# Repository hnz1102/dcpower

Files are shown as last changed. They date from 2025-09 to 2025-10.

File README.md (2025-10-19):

<div align="center">
  <h1><code>DC Power Unit for Breadboard</code></h1>
  <p>
    
  </p>
</div>

# DC Power Unit for Breadboard

This is a DC Power Unit for Breadboard based on ESP32-S3 microcontroller and AP33772S USB Power Delivery (PD) Sink Controller. It can supply power to the breadboard from USB Power Delivery (PD) Charger with support for both Standard Power Range (SPR) and Extended Power Range (EPR) modes. The output voltage can be controlled from 0v to 20V in SPR mode and up to 28V(*1) in EPR mode with step of 10mV.   
There are 2 types of adopters for the output terminal: Single positive power output terminal and dual positive/negative output terminal. It is easy to connect to the breadboard with standard 2.54mm pitch pin header. If you select the dual positive/negative output terminal adopter, the output voltage can be halved by positive and negative voltage. E.g. If you set the output voltage to 20V, you can get +10V and -10V from the positive and negative output terminal.

***1: Maximum voltage is limited to 28V by AP33772S hardware specifications. Some PD chargers may not support EPR mode or only support up to 16V/5A. Please check your PD charger specifications.**

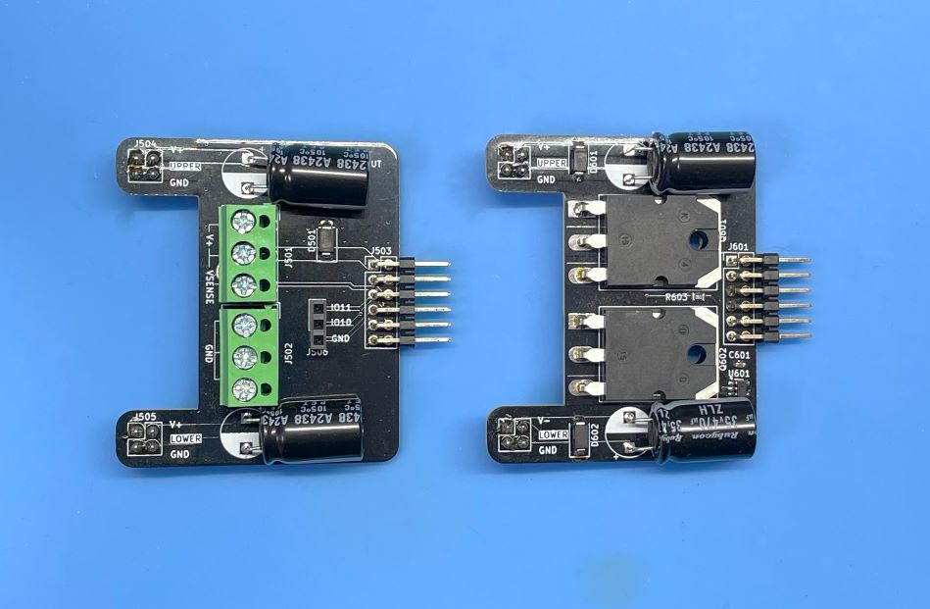
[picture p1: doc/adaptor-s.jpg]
adopter


The left image shows the single positive output terminal adopter, and the right image shows the dual positive/negative output terminal adopter.

## Key Features

- **High Power Delivery**: Up to 100W from USB PD Charger
- **Multiple Voltage Outputs**: 0V to 20V in SPR mode, 0V to 28V in EPR mode (10mV steps)
- **High Current Support**: Up to 5A when PD Charger supports EPR, but some chargers support up to 90% of the maximum current.
- **Touch Control Interface**: Front panel touch switch for voltage selection and output control
- **Precise Control**: PID controller maintains constant output voltage
- **High Accuracy Monitoring and Control**: 10mV voltage accuracy using shunt resistor and INA228 current sensor, with 1mV resolution.
- **Real-time Display**: OLED display shows voltage, current, power consumption, and temperature
- **Data Logging**: WiFi connectivity for sending measurement data to InfluxDB server
- **Web Dashboard**: Data visualization using InfluxDB dashboard
- **Safety Features**: Over Voltage Protection (OVP), Under Voltage Protection (UVP), Over Current Protection (OCP). Over Temperature Protection (OTP) does not implemented.

****Note**: If you use 21V or higher voltage, input voltage is 28v or higher, and differential voltage is over 3V and output current is over 3A, the MOSFET device is in the high consumption state and the unit temperature may rise over 80 degrees Celsius. Please be careful about the temperature. You can set the maximum temperature in the configuration file. The default value is 80 degrees Celsius. If the temperature exceeds the limit, the output will be disabled automatically. I recommend using less than 0.7A current at 21V or higher voltage. Otherwise, if you set the output voltage to 27V or higher, the temperature rise is not a problem.**

****Note**: This unit uses a micro controller and a USB PD controller. These controllers need the power to operate. Therefore, if you use a over current, the power source may be shut down by the over current protection of the PD charger. In this case, This unit cannot operate and will be turned off. Please use the current within the specification of your PD charger.**

## Hardware Components

- **ESP32-S3-WROOM-1-N16R8**: Main microcontroller
- **AP33772S**: USB Power Delivery Sink Controller with EPR support
- **INA228**: High-precision current/voltage sensor
- **SSD1331**: Color OLED display (96x64 pixels)
- **Touch Interface**: Capacitive touch sensors for user interaction
- **MOSFET Load Circuit**: Electronic load for testing and regulation

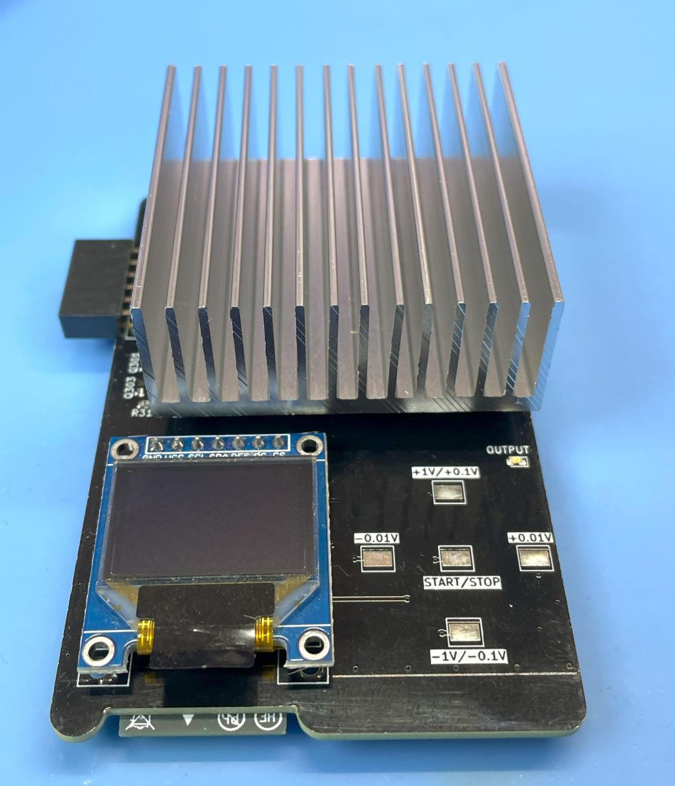
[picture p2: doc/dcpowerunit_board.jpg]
board


## Software Architecture

The firmware is written in Rust using the ESP-IDF framework and consists of several modules:

- `main.rs`: Main application logic and system initialization
- `usbpd.rs`: AP33772S USB-PD driver interface using the ap33772s-driver crate
- `displayctl.rs`: OLED display control and user interface
- `currentlogs.rs`: Current and voltage measurement using INA228
- `touchpad.rs`: Touch sensor interface and user input handling
- `pidcont.rs`: PID controller for voltage regulation
- `wifi.rs`: WiFi connectivity and network management
- `transfer.rs`: Data transmission to InfluxDB server
- `syslogger.rs`: System logging functionality

ap33772s-driver crate is used for USB-PD communication with the AP33772S controller. Please see the [ap33772s-driver](https://github.com/hnz1102/ap33772s-driver) for more details.

## How to Use the Unit

### Basic Operation

1. **Connection**: Connect a USB-C PD charger to the input port
2. **Power On**: The unit automatically detects the PD source and displays available power profiles
3. **Voltage Selection**: Use the touch interface to select desired output voltage
4. **Output Control**: Press the center touch position to enable/disable output
5. **Monitoring**: View real-time measurements on the OLED display

### Touch Interface Controls

- **Up/Down Touch**: Increase or decrease output voltage in 100mV steps, long press for 1V steps
- **Left/Right Touch**: Increase or decrease output voltage in 10mV steps
- **Center Touch**: Long press to toggle output ON/OFF
- **Display Information**: Shows current voltage, current, power, unit temperature, and WiFi status

**If the output is disabled due to over current, over power, or over temperature, you can clear the error message by pressing the center touch position once.**

### Safety Features

- Under Voltage Protection (UVP)
- Over Voltage Protection (OVP) 
- Over Current Protection (OCP)
- Automatic fault detection and shutdown

These protections are implemented by the AP33772S.

## Dependencies and Crates

The project uses the custom `ap33772s-driver` crate for USB-PD communication:

```toml
[dependencies]
ap33772s-driver = { version = "0.1.4", features = ["std"] }
```

Other key dependencies include:
- `esp-idf-hal` v0.45.2: ESP32 hardware abstraction
- `embedded-hal` v1.0.0: Platform-agnostic hardware interfaces
- `ssd1331` v0.3.0: OLED display driver
- `embedded-graphics` v0.7: Graphics primitives for display
- `chrono` v0.4.38: Date and time handling
- `toml-cfg` v0.1.3: Configuration file parsing

# How to build from code and Install to the unit.

Using Ubuntu 22.04.3 LTS and ESP-IDF V5.4.2

## Prerequisites
Ensure that your system meets the following requirements before proceeding with the installation:
- Operating System: Linux-based distribution
- Required Packages: git, python3, python3-pip, gcc, build-essential, curl, pkg-config, libudev-dev, libtinfo5, clang, libclang-dev, llvm-dev, udev, libssl-dev, python3.10-venv

## Installation Steps

### 1. System Update and Package Installation
Update your system and install the necessary packages using:
```bash
sudo apt update && sudo apt -y install git python3 python3-pip gcc build-essential curl pkg-config libudev-dev libtinfo5 clang libclang-dev llvm-dev udev libssl-dev python3.10-venv
```

### 2. Rust Installation
Install Rust programming language and Cargo package manager:
```bash
curl --proto '=https' --tlsv1.2 -sSf https://sh.rustup.rs | sh
```
After installation, activate Rust by sourcing the environment:
```bash
. "$HOME/.cargo/env"
```

### 3. Additional Tools Installation
Install the following Rust tools:
- ldproxy
- espup
- cargo-espflash

Use the following commands:
```bash
cargo install ldproxy
cargo install espup
cargo install cargo-espflash
```

At this time (2025-07-25), espup cannot be compiled. If you get an error, please use the following command to install the toolchain.
```bash
cargo install cargo-binstall
cargo binstall espup
```

### 4. ESP Environment Setup
Run the following command to install and update the Espressif Rust ecosystem:
```bash
espup install
espup update
```
Set up environment variables:
```bash
. ./export-esp.sh
```

### 5. Udev Rules Configuration
Configure udev rules for device permissions:
```bash
sudo sh -c 'echo "SUBSYSTEMS==\"usb\", ATTRS{idVendor}==\"303a\", ATTRS{idProduct}==\"1001\", MODE=\"0666\"" > /etc/udev/rules.d/99-esp32.rules'
sudo udevadm control --reload-rules
sudo udevadm trigger
```

### 6. Clone Repository
Clone the DC Power Unit repository:
```bash
git clone https://github.com/hnz1102/dcpower.git
cd dcpower/code
```

### 7. Setting WiFi SSID, Password, etc.
Change the following configuration file: `cfg.toml`
You have to set the following parameters: WiFi SSID, Password, InfluxDB Server IP Address, InfluxDB API Key, and InfluxDB API with your ORG.
You can get the API Key from the InfluxDB Web Console. Please see the 'How to Install the InfluxDB and Configure the Dashboard' section No.3.

```toml
[dcpowerunit]
wifi_ssid = "<Your AP SSID>"  # Set your AP SSID
wifi_psk = "<Your AP Password>" # Set your AP Password
influxdb_server = "<InfluxDB Server IP Address:Port>" # Set your InfluxDB Server IP Address and Port ex. 192.168.1.100:8086
pid_kp = "0.0000005"
pid_ki = "0.00002"
pid_kd = "0.1"
pwm_offset = "0"
pd_config_offset = "1.5"
shunt_resistance = "0.005"
shunt_temp_coefficient = "50"
max_current_limit = "5.2"
max_power_limit = "100.0"
max_temperature_limit = "75" # Set the maximum temperature limit in degrees Celsius. Default is 75 degrees.
influxdb_api_key = "<InfluxDB API KEY>" # Set your InfluxDB API Key
influxdb_api = "/api/v2/write?org=<ORG>&bucket=LOGGER&precision=ns" # Set your InfluxDB API with your ORG and BUCKET
influxdb_tag = "dcpowerunit"  # Tag for InfluxDB measurements
influxdb_measurement = "dcpowerunit" # Measurement name for InfluxDB
syslog_server = "<Syslog Server IP Address:Port>" # Set your Syslog Server IP Address and Port ex. 192.168.2.140:514
syslog_enable = "false" # Set to "true" to enable syslog
```

### 8. Build and Flash
Build the project:
```bash
cargo build --release
```

### 9. Flash the Firmware
Connect the DC Power Unit to your PC using a USB cable. Then, flash the firmware:
```bash
cargo espflash flash --release --monitor
```

If your device is not detected, power on the device and during the boot, press the `BOOT` button.
Then, run the flash command again.

### 10. Monitor the Output
After flashing the firmware, the console shows the booting messages and system initialization including:
- WiFi connection status
- AP33772S USB-PD controller initialization
- Available PDO (Power Data Object) detection
- Touch interface activation
- OLED display initialization
```bash
Chip type:         esp32s3 (revision v0.2)
Crystal frequency: 40 MHz
Flash size:        16MB
Features:          WiFi, BLE, Embedded Flash
MAC address:       80:65:99:b8:8e:90
App/part. size:    1,383,760/1,536,000 bytes, 90.09%
[00:00:00] [========================================]      14/14      0x0      Verifying... OK!                   
[00:00:00] [========================================]       1/1       0x8000   Skipped! (checksum matches)        
[00:00:15] [========================================]     864/864     0x10000  Verifying... OK!                   
[2025-09-15T07:23:38Z INFO ] Flashing has completed!
Commands:
    CTRL+R    Reset chip
    CTRL+C    Exit

ESP-ROM:esp32s3-20210327
Build:Mar 27 2021
rst:0x15 (USB_UART_CHIP_RESET),boot:0x8 (SPI_FAST_FLASH_BOOT)
Saved PC:0x40378d03
0x40378d03 - setup_priv_desc$isra$0
    at ??:??
SPIWP:0xee
mode:DIO, clock div:2
load:0x3fce2810,len:0x1564
load:0x403c8700,len:0x4
load:0x403c8704,len:0xd24
load:0x403cb700,len:0x2ed4
entry 0x403c8928
I (27) boot: ESP-IDF v5.4.2 2nd stage bootloader
I (27) boot: compile time Sep 15 2025 07:22:33
I (27) boot: Multicore bootloader
I (28) boot: chip revision: v0.2
I (30) boot: efuse block revision: v1.3
I (34) boot.esp32s3: Boot SPI Speed : 40MHz
I (38) boot.esp32s3: SPI Mode       : DIO
I (41) boot.esp32s3: SPI Flash Size : 16MB
I (45) boot: Enabling RNG early entropy source...
I (50) boot: Partition Table:
I (52) boot: ## Label            Usage          Type ST Offset   Length
I (59) boot:  0 nvs              WiFi data        01 02 00009000 00006000
I (65) boot:  1 phy_init         RF data          01 01 0000f000 00001000
I (72) boot:  2 factory          factory app      00 00 00010000 00177000
I (78) boot: End of partition table
I (81) esp_image: segment 0: paddr=00010020 vaddr=3c0f0020 size=4b244h (307780) map
I (164) esp_image: segment 1: paddr=0005b26c vaddr=3fc9c700 size=04dach ( 19884) load
I (170) esp_image: segment 2: paddr=00060020 vaddr=42000020 size=e89e8h (952808) map
I (404) esp_image: segment 3: paddr=00148a10 vaddr=3fca14ac size=00bfch (  3068) load
I (406) esp_image: segment 4: paddr=00149614 vaddr=40374000 size=186f0h (100080) load
I (437) esp_image: segment 5: paddr=00161d0c vaddr=600fe000 size=0001ch (    28) load
I (447) boot: Loaded app from partition at offset 0x10000
I (447) boot: Disabling RNG early entropy source...
I (457) octal_psram: vendor id    : 0x0d (AP)
I (457) octal_psram: dev id       : 0x02 (generation 3)
I (458) octal_psram: density      : 0x03 (64 Mbit)
I (460) octal_psram: good-die     : 0x01 (Pass)
I (464) octal_psram: Latency      : 0x01 (Fixed)
I (468) octal_psram: VCC          : 0x01 (3V)
I (472) octal_psram: SRF          : 0x01 (Fast Refresh)
I (477) octal_psram: BurstType    : 0x01 (Hybrid Wrap)
I (482) octal_psram: BurstLen     : 0x01 (32 Byte)
I (487) octal_psram: Readlatency  : 0x02 (10 cycles@Fixed)
I (492) octal_psram: DriveStrength: 0x00 (1/1)
I (497) MSPI Timing: PSRAM timing tuning index: 5
I (500) esp_psram: Found 8MB PSRAM device
I (504) esp_psram: Speed: 80MHz
I (507) cpu_start: Multicore app
I (522) cpu_start: Pro cpu start user code
I (522) cpu_start: cpu freq: 160000000 Hz
I (522) app_init: Application information:
I (522) app_init: Project name:     libespidf
I (526) app_init: App version:      100adf2
I (530) app_init: Compile time:     Sep 15 2025 07:22:02
I (535) app_init: ELF file SHA256:  000000000...
I (539) app_init: ESP-IDF:          v5.4.2
I (543) efuse_init: Min chip rev:     v0.0
I (547) efuse_init: Max chip rev:     v0.99 
I (551) efuse_init: Chip rev:         v0.2
I (555) heap_init: Initializing. RAM available for dynamic allocation:
I (561) heap_init: At 3FCA6A48 len 00042CC8 (267 KiB): RAM
I (566) heap_init: At 3FCE9710 len 00005724 (21 KiB): RAM
I (571) heap_init: At 3FCF0000 len 00008000 (32 KiB): DRAM
I (576) heap_init: At 600FE01C len 00001FCC (7 KiB): RTCRAM
I (582) esp_psram: Adding pool of 8192K of PSRAM memory to heap allocator
I (589) spi_flash: detected chip: gd
I (592) spi_flash: flash io: dio
W (595) pcnt(legacy): legacy driver is deprecated, please migrate to `driver/pulse_cnt.h`
W (602) i2c: This driver is an old driver, please migrate your application code to adapt `driver/i2c_master.h`
W (612) timer_group: legacy driver is deprecated, please migrate to `driver/gptimer.h`
I (620) sleep_gpio: Configure to isolate all GPIO pins in sleep state
I (626) sleep_gpio: Enable automatic switching of GPIO sleep configuration
I (633) main_task: Started on CPU0
I (643) esp_psram: Reserving pool of 32K of internal memory for DMA/internal allocations
I (643) main_task: Calling app_main()
I (653) gpio: GPIO[15]| InputEn: 0| OutputEn: 0| OpenDrain: 0| Pullup: 0| Pulldown: 0| Intr:0 
I (653) gpio: GPIO[16]| InputEn: 0| OutputEn: 0| OpenDrain: 0| Pullup: 0| Pulldown: 0| Intr:0 
I (663) gpio: GPIO[46]| InputEn: 0| OutputEn: 0| OpenDrain: 0| Pullup: 0| Pulldown: 0| Intr:0 
I (683) pp: pp rom version: e7ae62f
I (683) net80211: net80211 rom version: e7ae62f
I (693) wifi:wifi driver task: 3fcc44a0, prio:23, stack:6656, core=0
I (693) wifi:wifi firmware version: bea31f3
I (693) wifi:wifi certification version: v7.0
I (693) wifi:config NVS flash: disabled
I (693) wifi:config nano formatting: disabled
I (703) wifi:Init data frame dynamic rx buffer num: 32
I (703) wifi:Init static rx mgmt buffer num: 5
I (713) wifi:Init management short buffer num: 32
I (713) wifi:Init dynamic tx buffer num: 32
I (723) wifi:Init static tx FG buffer num: 2
I (723) wifi:Init static rx buffer size: 1600
I (723) wifi:Init static rx buffer num: 10
I (733) wifi:Init dynamic rx buffer num: 32
I (733) wifi_init: rx ba win: 6
I (733) wifi_init: accept mbox: 6
I (743) wifi_init: tcpip mbox: 32
I (743) wifi_init: udp mbox: 6
I (743) wifi_init: tcp mbox: 6
I (753) wifi_init: tcp tx win: 5760
I (753) wifi_init: tcp rx win: 5760
I (753) wifi_init: tcp mss: 1440
I (763) wifi_init: WiFi IRAM OP enabled
I (763) wifi_init: WiFi RX IRAM OP enabled
I (773) phy_init: phy_version 701,f4f1da3a,Mar  3 2025,15:50:10
I (803) wifi:mode : sta (80:65:99:b8:8e:90)
I (803) wifi:enable tsf
I (3313) wifi:new:<8,0>, old:<1,0>, ap:<255,255>, sta:<8,0>, prof:1, snd_ch_cfg:0x0
I (3313) wifi:state: init -> auth (0xb0)
I (3313) wifi:state: auth -> assoc (0x0)
I (3323) wifi:state: assoc -> run (0x10)
I (3333) wifi:connected with Buffalo-G-1AD0, aid = 4, channel 8, BW20, bssid = c4:3c:ea:df:1a:d0
I (3333) wifi:security: WPA2-PSK, phy: bgn, rssi: -51
I (3333) wifi:pm start, type: 1

I (3333) wifi:dp: 1, bi: 102400, li: 3, scale listen interval from 307200 us to 307200 us
I (3343) wifi:set rx beacon pti, rx_bcn_pti: 0, bcn_timeout: 25000, mt_pti: 0, mt_time: 10000
I (3423) wifi:AP's beacon interval = 102400 us, DTIM period = 1
I (5353) esp_netif_handlers: sta ip: 192.168.2.142, mask: 255.255.255.0, gw: 192.168.2.1
I (9063) wifi:<ba-add>idx:0 (ifx:0, c4:3c:ea:df:1a:d0), tid:0, ssn:3, winSize:64
I (13373) wifi:<ba-add>idx:1 (ifx:0, c4:3c:ea:df:1a:d0), tid:2, ssn:0, winSize:64
I (13383) gpio: GPIO[18]| InputEn: 0| OutputEn: 0| OpenDrain: 0| Pullup: 0| Pulldown: 0| Intr:0 
I (13393) gpio: GPIO[9]| InputEn: 0| OutputEn: 0| OpenDrain: 0| Pullup: 0| Pulldown: 0| Intr:0 
```

## How to Install the influxDB and Configure the Dashboard

### 1. Download [influxDB](https://docs.influxdata.com/influxdb/v2.7/install/?t=Linux) and Install.
```bash
$ wget https://dl.influxdata.com/influxdb/releases/influxdb2-2.7.0-amd64.deb
$ sudo dpkg -i influxdb2-2.7.0-amd64.deb
$ sudo service influxdb start
```

### 2. Configure the influxDB

```
Connect to the 'http://<influxDB installed PC Address>:8086'
```
Click `GET STARTED` and set `Username`, `Password`, `Initial Organization Name`, and `Initial Bucket Name`
|Term|Value|
|---|---|
|Username|Set login username as influxDB administrator web console|
|Password|Set login password as influxDB administrator web console|
|Initial Organization Name| Organization Name ex. ORG|
|Initial Bucket Name| LOGGER |

After set them, click `CONTINUE`.

### 3. Copy the operator API token.

You can see the operator API token on the browser. YOU WON'T BE ABLE TO SEE IT AGAIN!
If you want to get new API token, click `API Tokens` menu form `Sources` Icon, then click `GENERATE API TOKEN` and select `All access token`, click `Save`.
You can see a new API token and get it.
After copy the token, click `CONFIGURE LATER`.

### 4. Import the Dashboard Template.

Click the `Dashboard` icon, and select `Import Dashboard` from the `CREATE DASHBOARD` menu.

Drop the `influxdb/dc_power_station.json` file to `Drop a file here`, then click `IMPORT JSON AS DASHBOARD`.

You can see the `DC POWER STATION` pannel on the Dashboards page.

Click this panel, and You can see the dashboard.

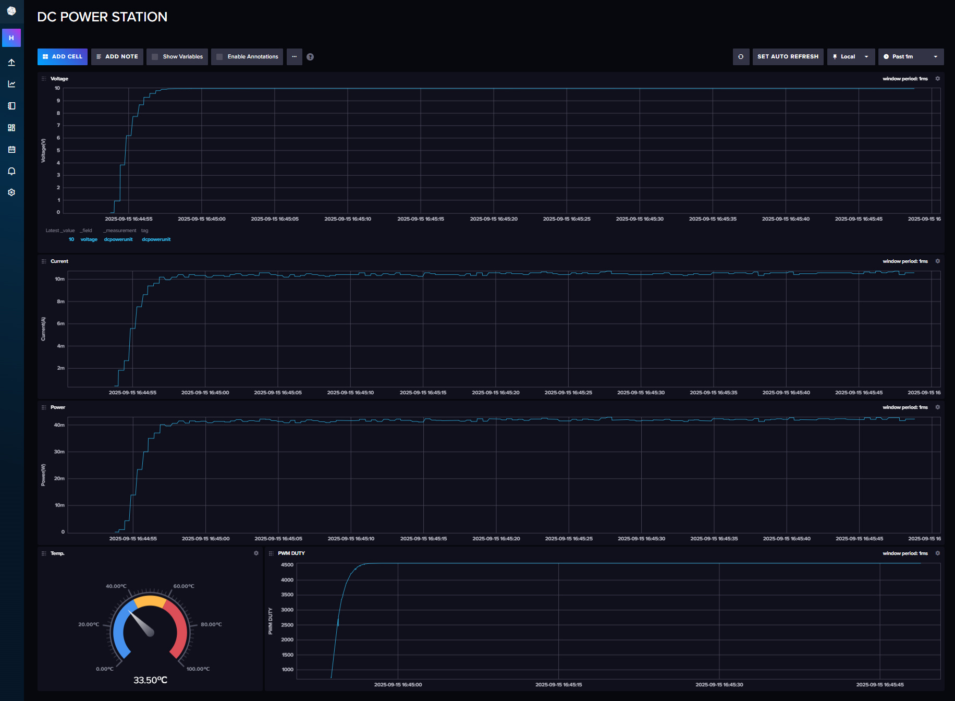
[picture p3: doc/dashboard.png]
dashboard


If you want to customize the dashboard design, click configure mark. You can change the graph design.

## Schematic, PCB Gabar Data

There is a Schematic data in hardware directory. 

This PCB is designed by [Kicad](https://www.kicad.org/). 

## LICENSE
This source code is licensed under MIT. Other Hardware Schematic documents are licensed under CC-BY-SA V4.0.

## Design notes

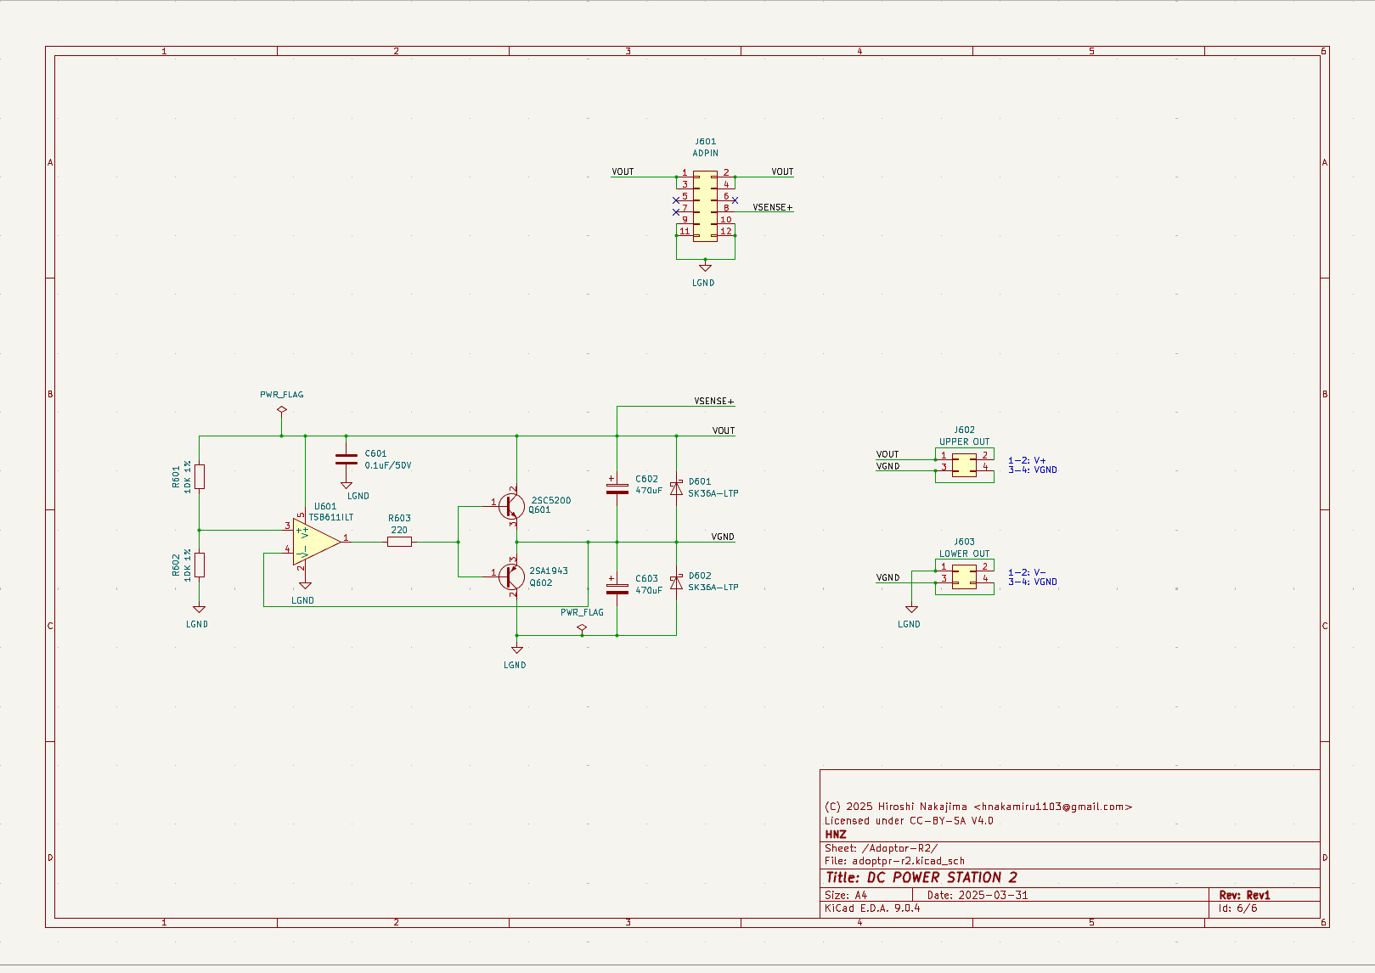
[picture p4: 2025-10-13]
doc/schematic5.png

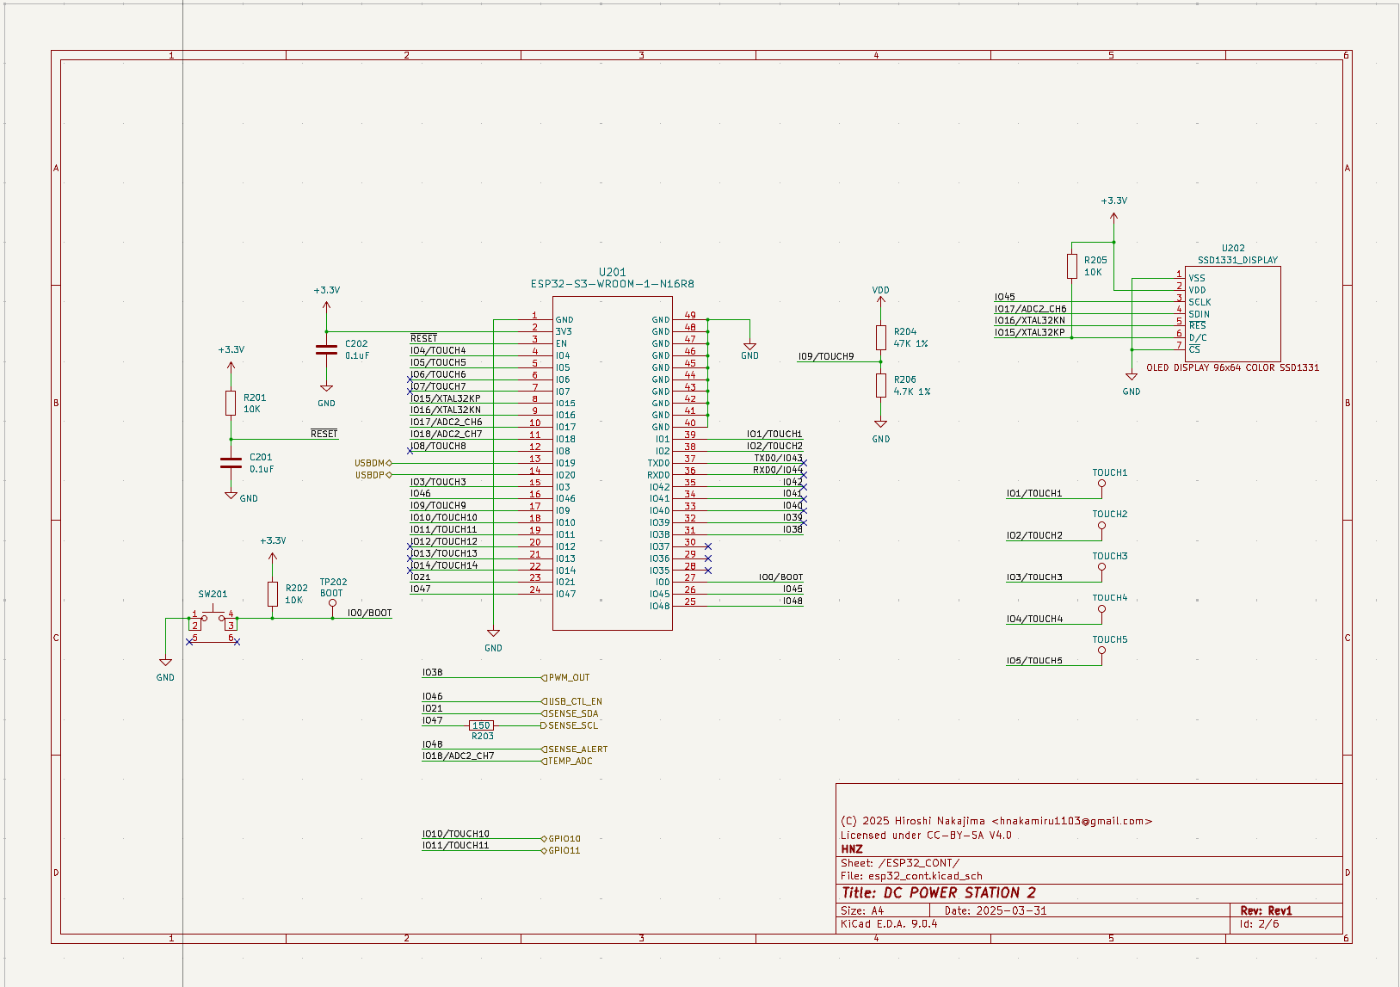
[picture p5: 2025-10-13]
doc/schematic2.png

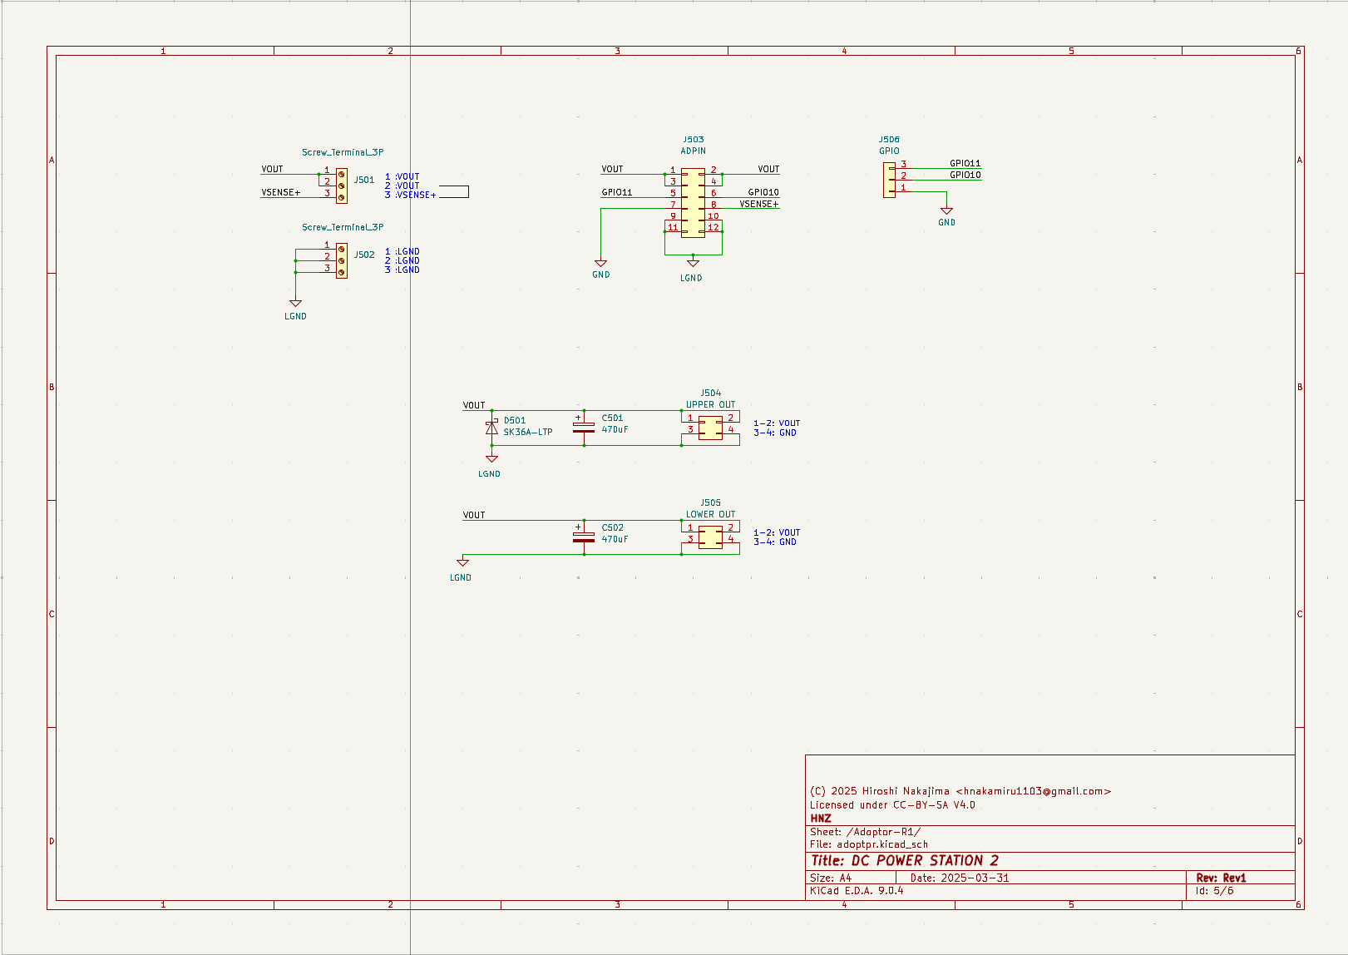
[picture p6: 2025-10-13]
doc/schematic4.png

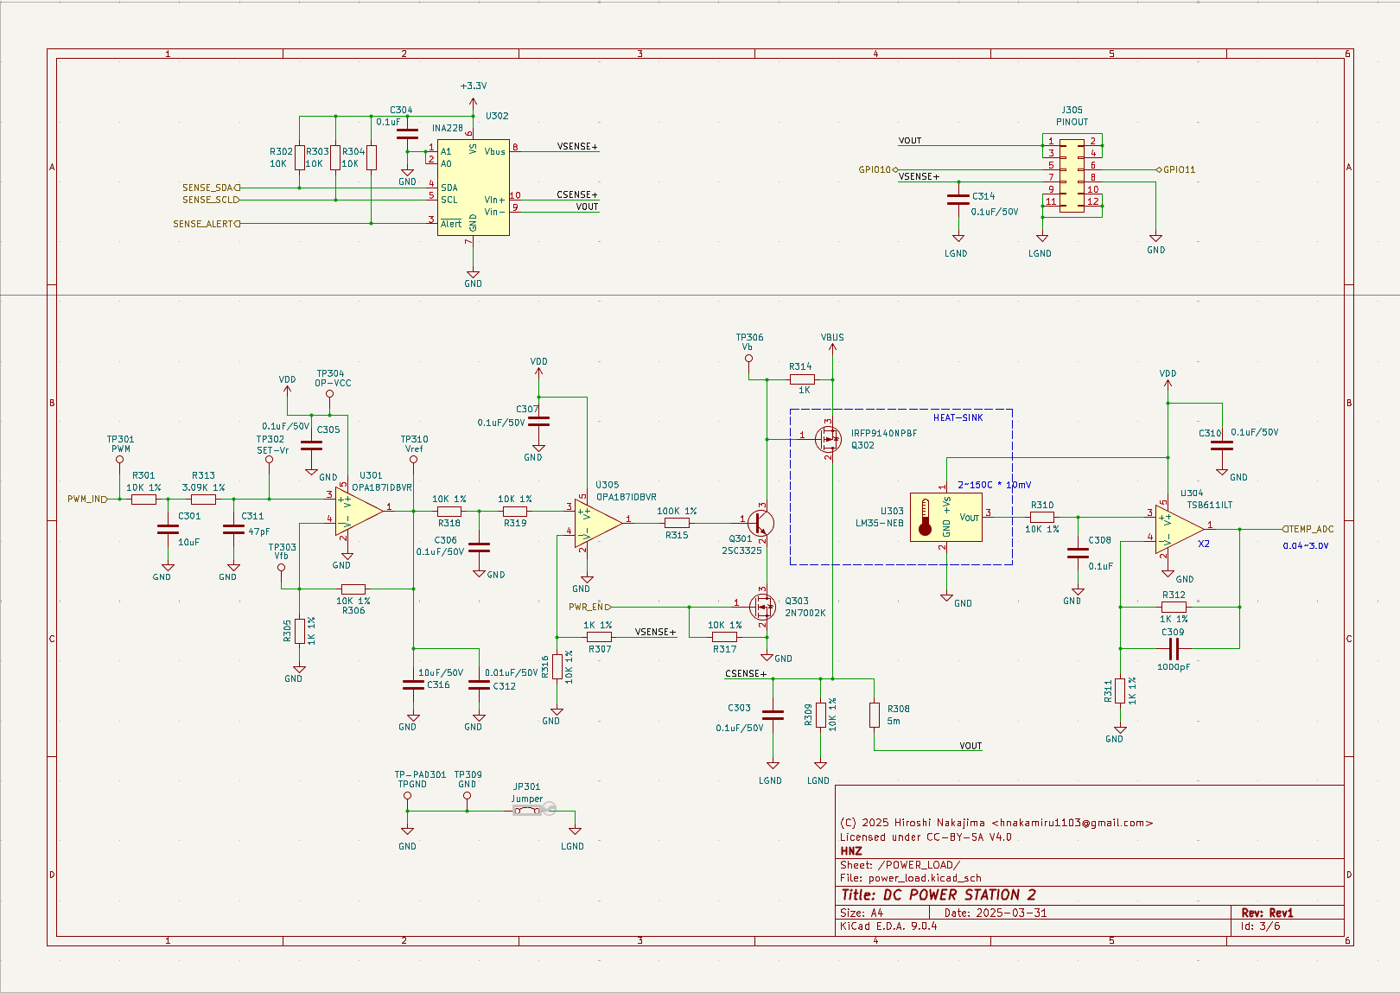
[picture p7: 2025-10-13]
doc/schematic3.png

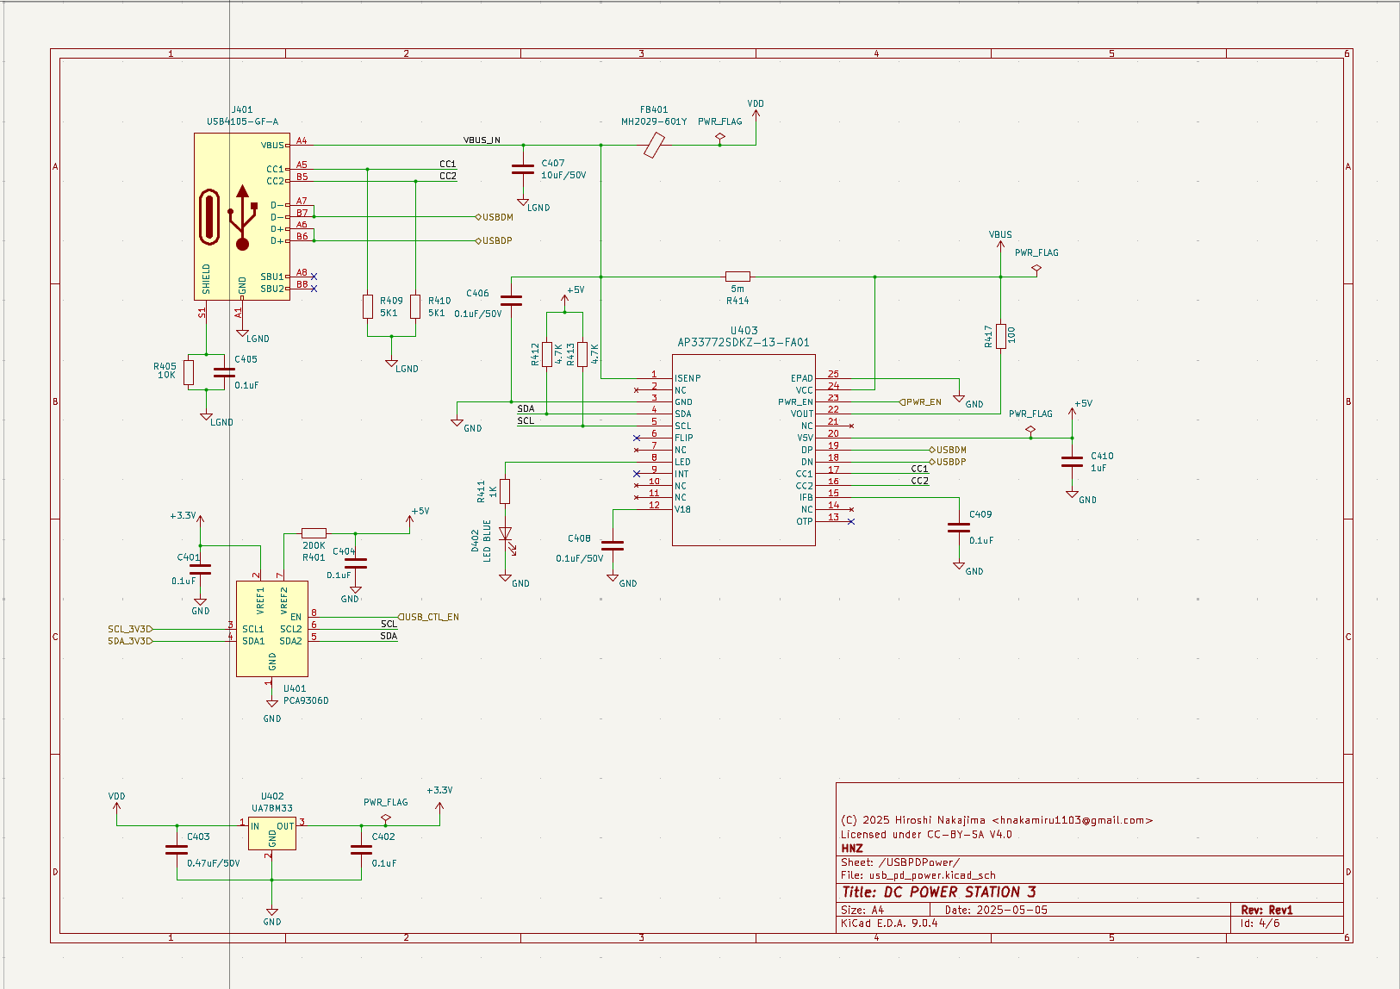
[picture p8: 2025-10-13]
doc/schematic1.png

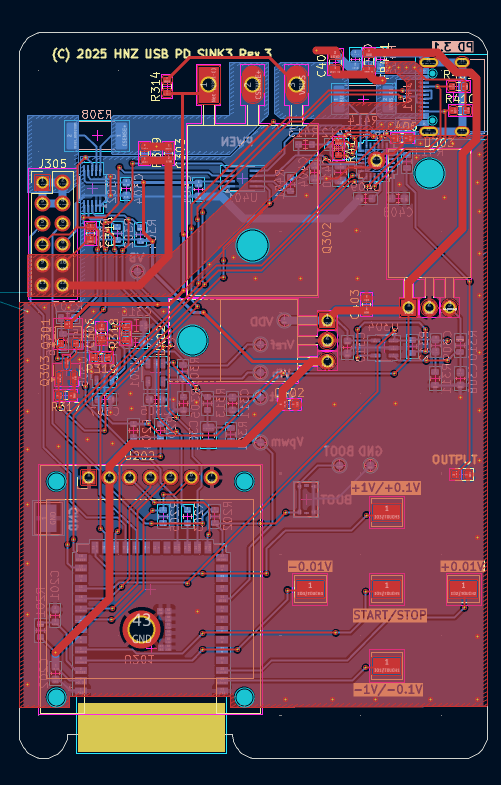
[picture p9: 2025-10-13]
doc/main-pcb.png

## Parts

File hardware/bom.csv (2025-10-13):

Reference | Value | Datasheet | Footprint | Qty | DNP | digikey | distributor | storeURL
C201,C202,C304,C308,C401,C402,C404,C405,C409 | 0.1uF | ~ | Capacitor_SMD:C_0603_1608Metric | 9 |  | 311-1343-1-ND | https://www.digikey.com/en/products/detail/yageo/CC0603ZRY5V9BB104/2103081
C301 | 10uF | ~ | Capacitor_SMD:C_0805_2012Metric | 1 |  | 490-6473-1-ND | https://www.digikey.com/en/products/detail/murata-electronics/GRM21BR61C106KE15K/2546903
C303,C305,C306,C307,C310,C314,C406,C408,C601 | 0.1uF/50V | ~ | Capacitor_SMD:C_0603_1608Metric | 9 |  | 311-1343-1-ND | https://www.digikey.com/en/products/detail/yageo/CC0603ZRY5V9BB104/2103081
C309 | 1000pF | ~ | Capacitor_SMD:C_0603_1608Metric | 1 |  | 311-1080-1-ND | https://www.digikey.com/en/products/detail/yageo/CC0603KRX7R9BB102/302814
C311 | 47pF | ~ | Capacitor_SMD:C_0603_1608Metric | 1 |  | 311-3980-1-ND | https://www.digikey.com/en/products/detail/yageo/CC0603JRNPOABN470/5883631
C312 | 0.01uF/50V | ~ | Capacitor_SMD:C_0603_1608Metric | 1 |  | 311-1085-1-ND | https://www.digikey.com/en/products/detail/yageo/CC0603KRX7R9BB103/302819
C316,C407 | 10uF/50V | ~ | Capacitor_SMD:C_0805_2012Metric | 2 |  | 490-18663-1-ND | https://www.digikey.com/en/products/detail/murata-electronics/GRM21BR61H106KE43L/10326316
C403 | 0.47uF/50V | ~ | Capacitor_SMD:C_0603_1608Metric | 1 |  | 587-3170-1-ND | https://www.digikey.com/en/products/detail/taiyo-yuden/UMK107B7474KA-TR/3194963
C410 | 1uF | ~ | Capacitor_SMD:C_0805_2012Metric | 1 |  | 311-1365-1-ND | https://www.digikey.jp/en/products/detail/yageo/CC0805KKX7R7BB105/2103103
C501,C502,C602,C603 | 470uF | ~ | Capacitor_THT:CP_Radial_D8.0mm_P5.00mm | 4 |  | 1189-1890-ND | https://www.digikey.jp/en/products/detail/rubycon/35ZLH470MEFC10X16/3563723
D402 | LED BLUE | ~ | LED_SMD:LED_0603_1608Metric | 1 |  | 3147-B1931NB--20C007614U1930CT-ND | https://www.digikey.jp/en/products/detail/harvatek-corporation/B1931NB-20C007614U1930/15861263
D501,D601,D602 | SK36A-LTP |  | Diode_SMD:D_SMA | 3 |  | SK36A-LTPMSCT-ND | https://www.digikey.com/en/products/detail/mcc-micro-commercial-components/SK36A-LTP/2642025
FB401 | MH2029-601Y | ~ | Inductor_SMD:L_0805_2012Metric | 1 |  | MH2029-601YCT-ND | https://www.digikey.com/en/products/detail/bourns-inc/MH2029-601Y/3741762
J305 | PINOUT | ~ | Connector_PinHeader_2.54mm:PinHeader_2x06_P2.54mm_Vertical | 1 |  | PPPC062LJBN-RC | https://www.digikey.com/en/products/detail/sullins-connector-solutions/PPPC062LJBN-RC/776017
J401 | USB4105-GF-A | https://www.usb.org/sites/default/files/documents/usb_type-c.zip | Library:USB_C_5077CR-16-SMC2-BK-TR | 1 |  | 2073-USB4105-GF-ACT-ND | https://www.digikey.com/en/products/detail/gct/USB4105-GF-A/11198441
J501,J502 | Screw_Terminal_3P | ~ | Library:TB112-2-2-3-E-1 Terminal Block | 2 |  | A113321-ND | https://akizukidenshi.com/catalog/g/g101310/
J503,J601 | ADPIN | ~ | Connector_PinHeader_2.54mm:PinHeader_2x06_P2.54mm_Vertical | 2 |  | 2057-PH2RA-12-UA-ND | https://www.digikey.jp/en/products/detail/adam-tech/PH2RA-12-UA/9830569
J504,J602 | UPPER OUT | ~ | Connector_PinHeader_2.54mm:PinHeader_2x02_P2.54mm_Vertical | 2 |  | 2057-PH2-04-UA-ND | https://www.digikey.jp/en/products/detail/adam-tech/PH2-04-UA/9830324
J505,J603 | LOWER OUT | ~ | Connector_PinHeader_2.54mm:PinHeader_2x02_P2.54mm_Vertical | 2 |  | 2057-PH2-04-UA-ND | https://www.digikey.jp/en/products/detail/adam-tech/PH2-04-UA/9830324
J506 | GPIO | ~ | Connector_PinHeader_2.54mm:PinHeader_1x03_P2.54mm_Vertical | 1 |  | 2057-RS1-03-G-ND | https://www.digikey.jp/en/products/detail/adam-tech/RS1-03-G/9832055
JP301 | Jumper | ~ | Jumper:SolderJumper-2_P1.3mm_Bridged_RoundedPad1.0x1.5mm | 1 |  | -
Q301 | 2SC3325 |  | Package_TO_SOT_SMD:SC-59 | 1 |  | 2SC3325-YLFCT-ND
Q302 | IRFP9140NPBF |  | Package_TO_SOT_THT:TO-247-3_Horizontal_TabUp | 1 |  | IRFP9140NPBF-ND | https://www.digikey.com/en/products/detail/infineon-technologies/IRFP9140NPBF/811643
Q303 | 2N7002K | https://www.diodes.com/assets/Datasheets/ds30896.pdf | Package_TO_SOT_SMD:SOT-23 | 1 |  | 2N7002KCT-ND
Q601 | 2SC5200 |  | Package_TO_SOT_THT:TO-3P-3_Horizontal_TabDown | 1 |  | 5272-2SC5200-ND | https://www.digikey.com/en/products/detail/evvo/2SC5200/22674673
Q602 | 2SA1943 |  | Package_TO_SOT_THT:TO-3P-3_Horizontal_TabDown | 1 |  | 5272-2SA1943-ND | https://www.digikey.com/en/products/detail/evvo/2SA1943/22674744
R201,R202,R205,R302,R303,R304,R405 | 10K | ~ | Resistor_SMD:R_0603_1608Metric | 7 |  | 13-RC0603JR-1010KLCT-ND | https://www.digikey.com/en/products/detail/yageo/RC0603JR-1010KL/13694233
R203 | 150 | ~ | Resistor_SMD:R_0603_1608Metric | 1 |  | 311-150GRCT-ND | https://www.digikey.jp/en/products/detail/yageo/RC0603JR-07150RL/726714
R204 | 47K 1% | ~ | Resistor_SMD:R_0603_1608Metric | 1 |  | 311-47.0KHRCT-ND | https://www.digikey.com/en/products/detail/yageo/RC0603FR-0747KL/727253
R206 | 4.7K 1% | ~ | Resistor_SMD:R_0603_1608Metric | 1 |  | 311-4.70KHRCT-ND | https://www.digikey.com/en/products/detail/yageo/RC0603FR-074K7L/727212
R301,R306,R309,R310,R316,R317,R318,R319,R601,R602 | 10K 1% | ~ | Resistor_SMD:R_0603_1608Metric | 10 |  | 311-10.0KHRCT-ND | https://www.digikey.jp/en/products/detail/yageo/RC0603FR-0710KL/726880
R305,R307,R311,R312 | 1K 1% | ~ | Resistor_SMD:R_0603_1608Metric | 4 |  | YAG2323CT-ND | https://www.digikey.jp/en/products/detail/yageo/RC0603FR-071KL/726843
R308,R414 | 5m | ~ | Resistor_SMD:R_2512_6332Metric_Pad1.40x3.35mm_HandSolder | 2 |  | 4506-PEWF2512D5L00Q9CT-ND | https://www.digikey.com/en/products/detail/resi/PEWF2512D5L00Q9/24372530
R313 | 3.09K 1% | ~ | Resistor_SMD:R_0603_1608Metric | 1 |  | 311-3.09KHRCT-ND | https://www.digikey.com/en/products/detail/yageo/RC0603FR-073K09L/727123
R314,R411 | 1K | ~ | Resistor_SMD:R_0603_1608Metric | 2 |  | 13-RC0603JR-1010KLCT-ND | https://www.digikey.com/en/products/detail/yageo/RC0603JR-1010KL/13694233
R315 | 100K 1% | ~ | Resistor_SMD:R_0603_1608Metric | 1 |  | 311-100KHRCT-ND | https://www.digikey.jp/en/products/detail/yageo/RC0603FR-07100KL/726889
R401 | 200K | ~ | Resistor_SMD:R_0603_1608Metric | 1 |  | 311-200KHRCT-ND | https://www.digikey.com/en/products/detail/yageo/RC0603FR-07200KL/727044
R409,R410 | 5K1 | ~ | Resistor_SMD:R_0603_1608Metric | 2 |  | 311-5.10KHRCT-ND | https://www.digikey.com/en/products/detail/yageo/RC0603FR-075K1L/727268
R412,R413 | 4.7K | ~ | Resistor_SMD:R_0603_1608Metric | 2 |  | 311-4.70KHRCT-ND | https://www.digikey.jp/en/products/detail/yageo/RC0603FR-074K7L/727212
R417 | 100 | ~ | Resistor_SMD:R_0603_1608Metric | 1 |  | 311-100GRCT-ND | https://www.digikey.jp/en/products/detail/yageo/RC0603JR-07100RL/726697
R603 | 220 | ~ | Resistor_SMD:R_0603_1608Metric | 1 |  | 311-220GRCT-ND | https://www.digikey.com/en/products/detail/yageo/RC0603JR-07220RL/726741
SW201 | 3.5x2.6 Tact SW |  | Library:WS-TASV SMT Tact Switch | 1 |  | 732-435151014824CT-ND | https://www.digikey.com/en/products/detail/w%C3%BCrth-elektronik/435151014824/11627325
TP-PAD201 | TOUCH1 | ~ | Library:TestPoint_Pad_3.2x1.6mm | 1 |  | -
TP-PAD202 | TOUCH2 | ~ | Library:TestPoint_Pad_3.2x1.6mm | 1 |  | -
TP-PAD203 | TOUCH3 | ~ | Library:TestPoint_Pad_3.2x1.6mm | 1 |  | -
TP-PAD204 | TOUCH4 | ~ | Library:TestPoint_Pad_3.2x1.6mm | 1 |  | -
TP-PAD205 | TOUCH5 | ~ | Library:TestPoint_Pad_3.2x1.6mm | 1 |  | -
TP-PAD301 | TPGND | ~ | Library:TestPoint_Pad_3.2x1.6mm | 1 |  | 2019-RCWCTECT-ND | https://www.digikey.com/en/products/detail/koa-speer-electronics-inc/RCWCTE/11476558
TP202 | BOOT | ~ | TestPoint:TestPoint_Pad_D1.0mm | 1 |  | -
TP301 | PWM | ~ | TestPoint:TestPoint_Pad_D1.0mm | 1 |  | -
TP302 | SET-Vr | ~ | TestPoint:TestPoint_Pad_D1.0mm | 1 |  | -
TP303 | Vfb | ~ | TestPoint:TestPoint_Pad_D1.0mm | 1 |  | -
TP304 | OP-VCC | ~ | TestPoint:TestPoint_Pad_D1.0mm | 1 |  | -
TP306 | Vb | ~ | TestPoint:TestPoint_Pad_D1.0mm | 1 |  | -
TP309 | GND | ~ | TestPoint:TestPoint_Pad_D1.0mm | 1 |  | -
TP310 | Vref | ~ | TestPoint:TestPoint_Pad_D1.0mm | 1 |  | -
U201 | ESP32-S3-WROOM-1-N16R8 | ESP32-S3-WROOM-1-N16R2 | Library:ESP32-S3-WROOM-1_EXP | 1 |  | 1965-ESP32-S3-WROOM-1-N16R8CT-ND | https://www.digikey.com/en/products/detail/espressif-systems/ESP32-S3-WROOM-1-N16R8/16162642
U202 | SSD1331_DISPLAY |  | Library:OLED SSD1331 SPI DISPLAY | 1 |  | 3190-DLC0095ANOB-1-ND | https://akizukidenshi.com/catalog/g/gP-14435/
U301,U305 | OPA187IDBVR |  | Package_TO_SOT_SMD:SOT-23-5 | 2 |  | 296-53156-1-ND | https://www.digikey.com/en/products/detail/texas-instruments/OPA187IDBVR/9861469
U302 | INA228 | http://www.ti.com/lit/ds/symlink/ina226.pdf | Package_SO:VSSOP-10_3x3mm_P0.5mm | 1 |  | 296-INA228AIDGSRCT-ND | https://www.digikey.com/en/products/detail/texas-instruments/INA228AIDGSR/13691042
U303 | LM35-NEB | http://www.ti.com/lit/ds/symlink/lm35.pdf | Package_TO_SOT_THT:TO-220-3_Horizontal_TabDown | 1 |  | LM35DT/NOPB-ND | https://www.digikey.jp/en/products/detail/texas-instruments/LM35DT-NOPB/362706
U304,U601 | TSB611ILT |  | Package_TO_SOT_SMD:SOT-23-5 | 2 |  | 497-16082-1-ND | https://www.digikey.jp/en/products/detail/stmicroelectronics/TSB611ILT/5639707
U401 | PCA9306D | https://www.nxp.com/docs/en/data-sheet/PCA9306.pdf | Package_SO:SSOP-8_2.95x2.8mm_P0.65mm | 1 |  | 568-4215-1-ND | https://www.digikey.com/en/products/detail/nxp-usa-inc/PCA9306D-118/1300968
U402 | UA78M33 |  | Package_TO_SOT_THT:TO-220-3_Horizontal_TabUp | 1 |  | 296-13424-1-ND | https://www.digikey.com/en/products/detail/texas-instruments/UA78M33CDCYR/484638
U403 | AP33772SDKZ-13-FA01 | AP33772SDKZ-13 | Library:W-QFN4040-24_Type_A1_DIO | 1 |  | 31-AP33772SDKZ-13-FA01CT-ND | https://www.digikey.com/en/products/detail/diodes-incorporated/AP33772SDKZ-13-FA01/24765045

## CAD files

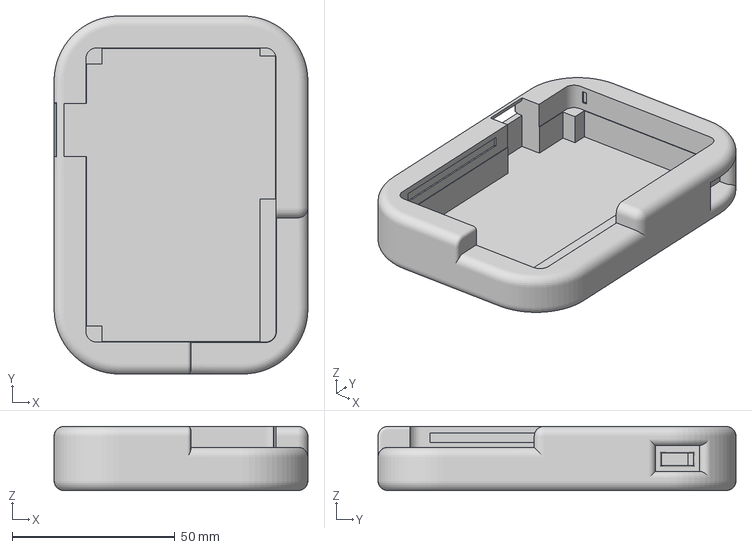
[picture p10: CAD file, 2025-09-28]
hardware/Container/body.3mf
78.0 x 110.0 x 19.7 mm

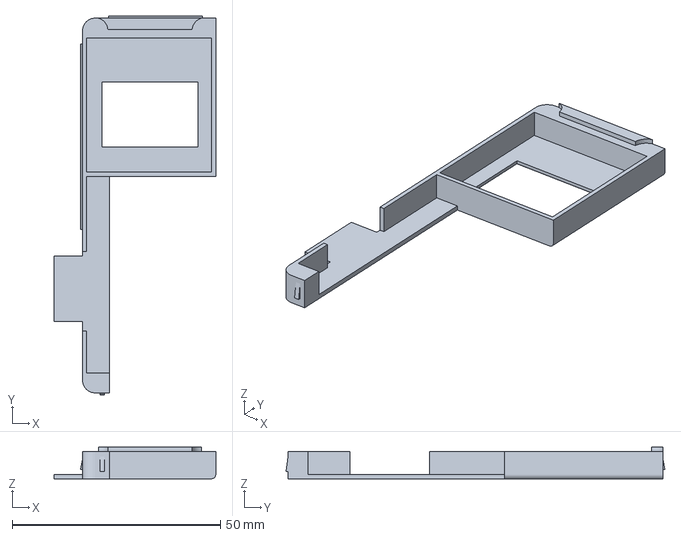
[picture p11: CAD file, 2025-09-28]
hardware/Container/upper-v7.3mf
38.8 x 91.0 x 7.60 mm

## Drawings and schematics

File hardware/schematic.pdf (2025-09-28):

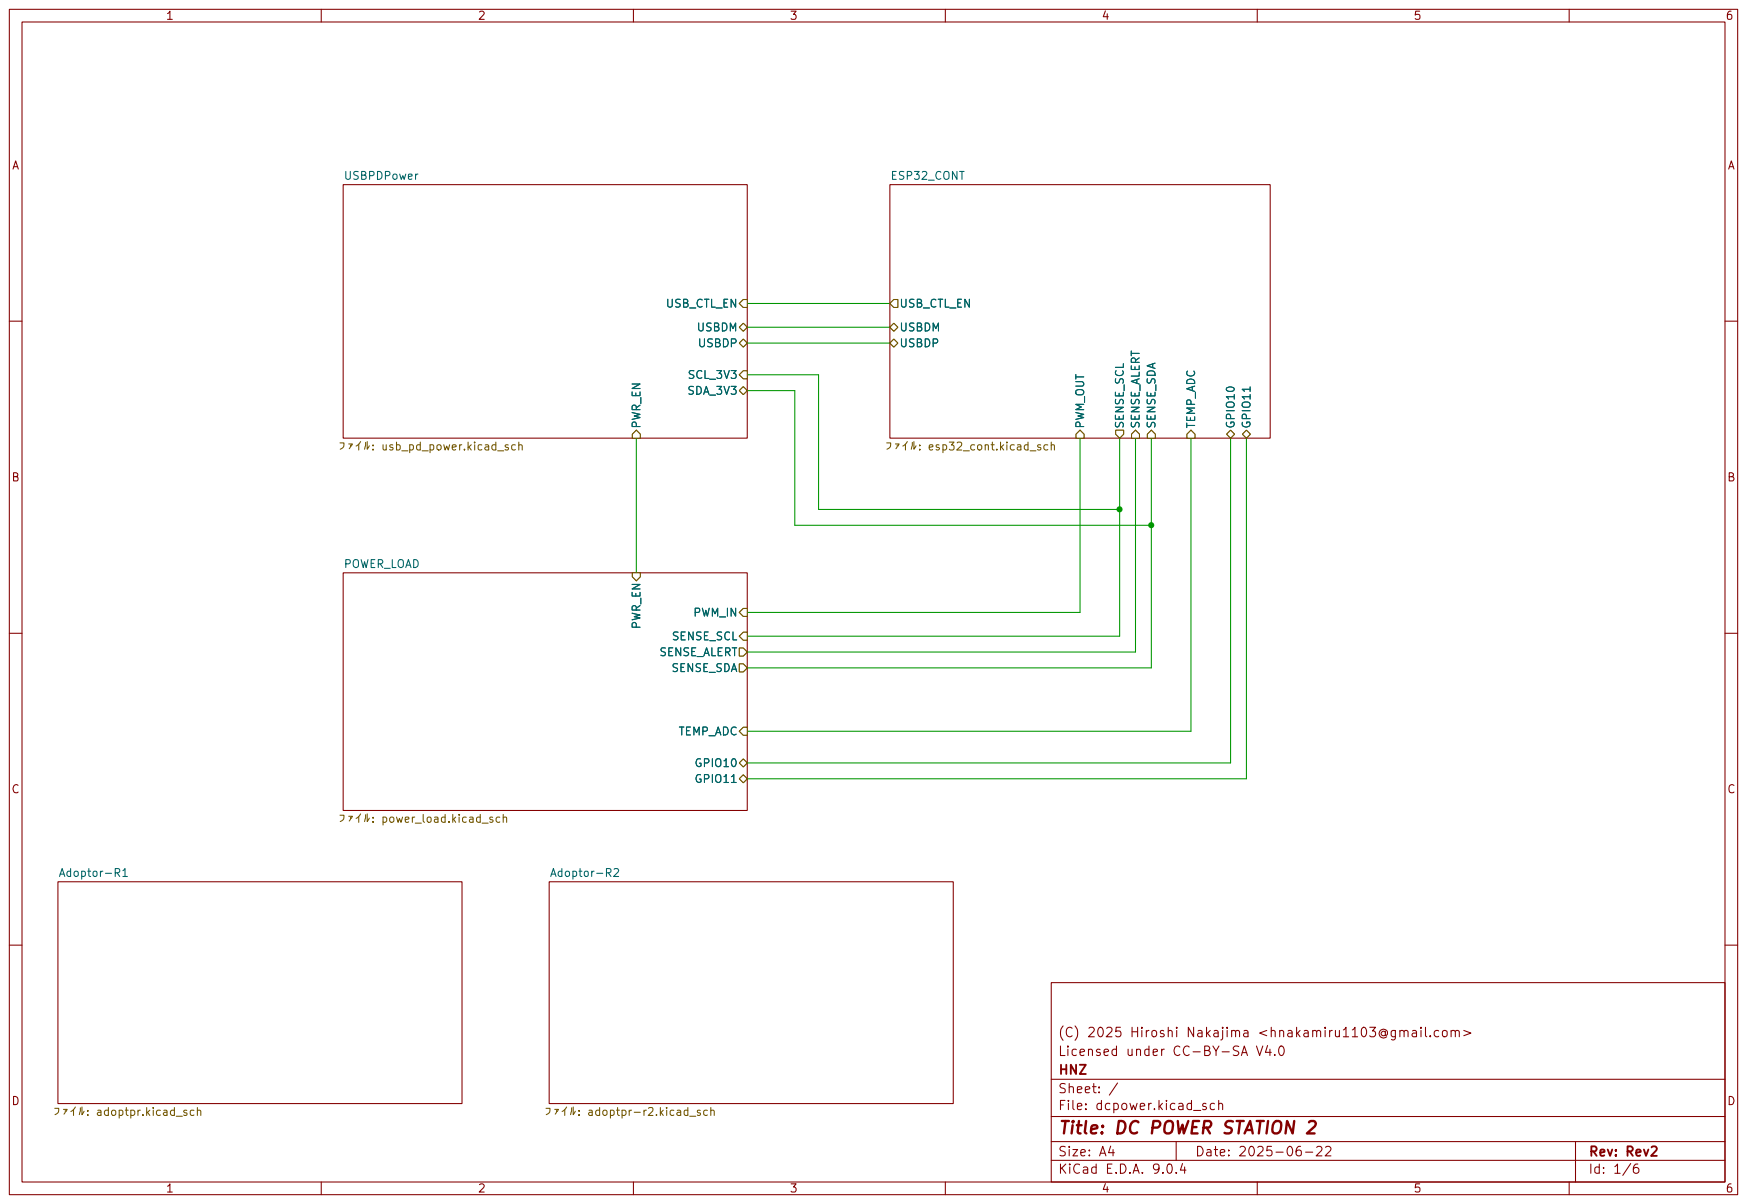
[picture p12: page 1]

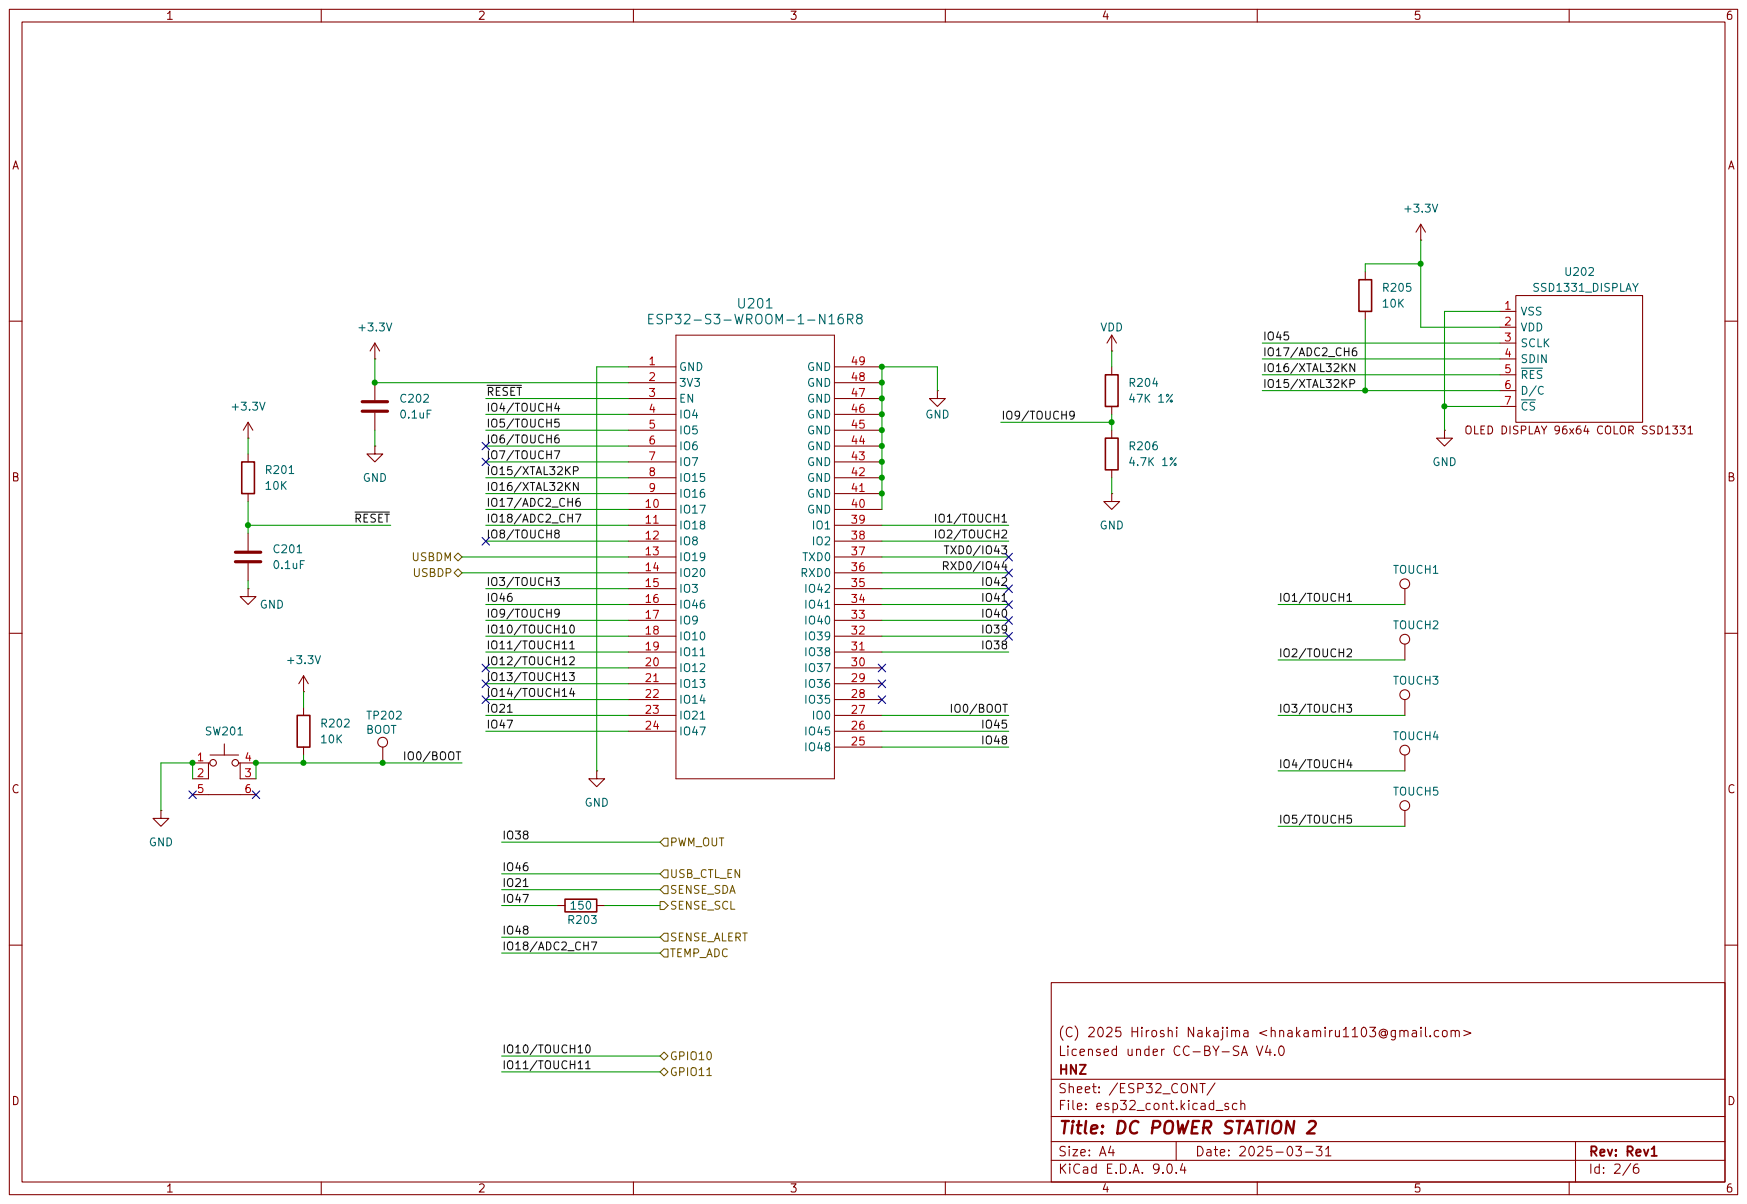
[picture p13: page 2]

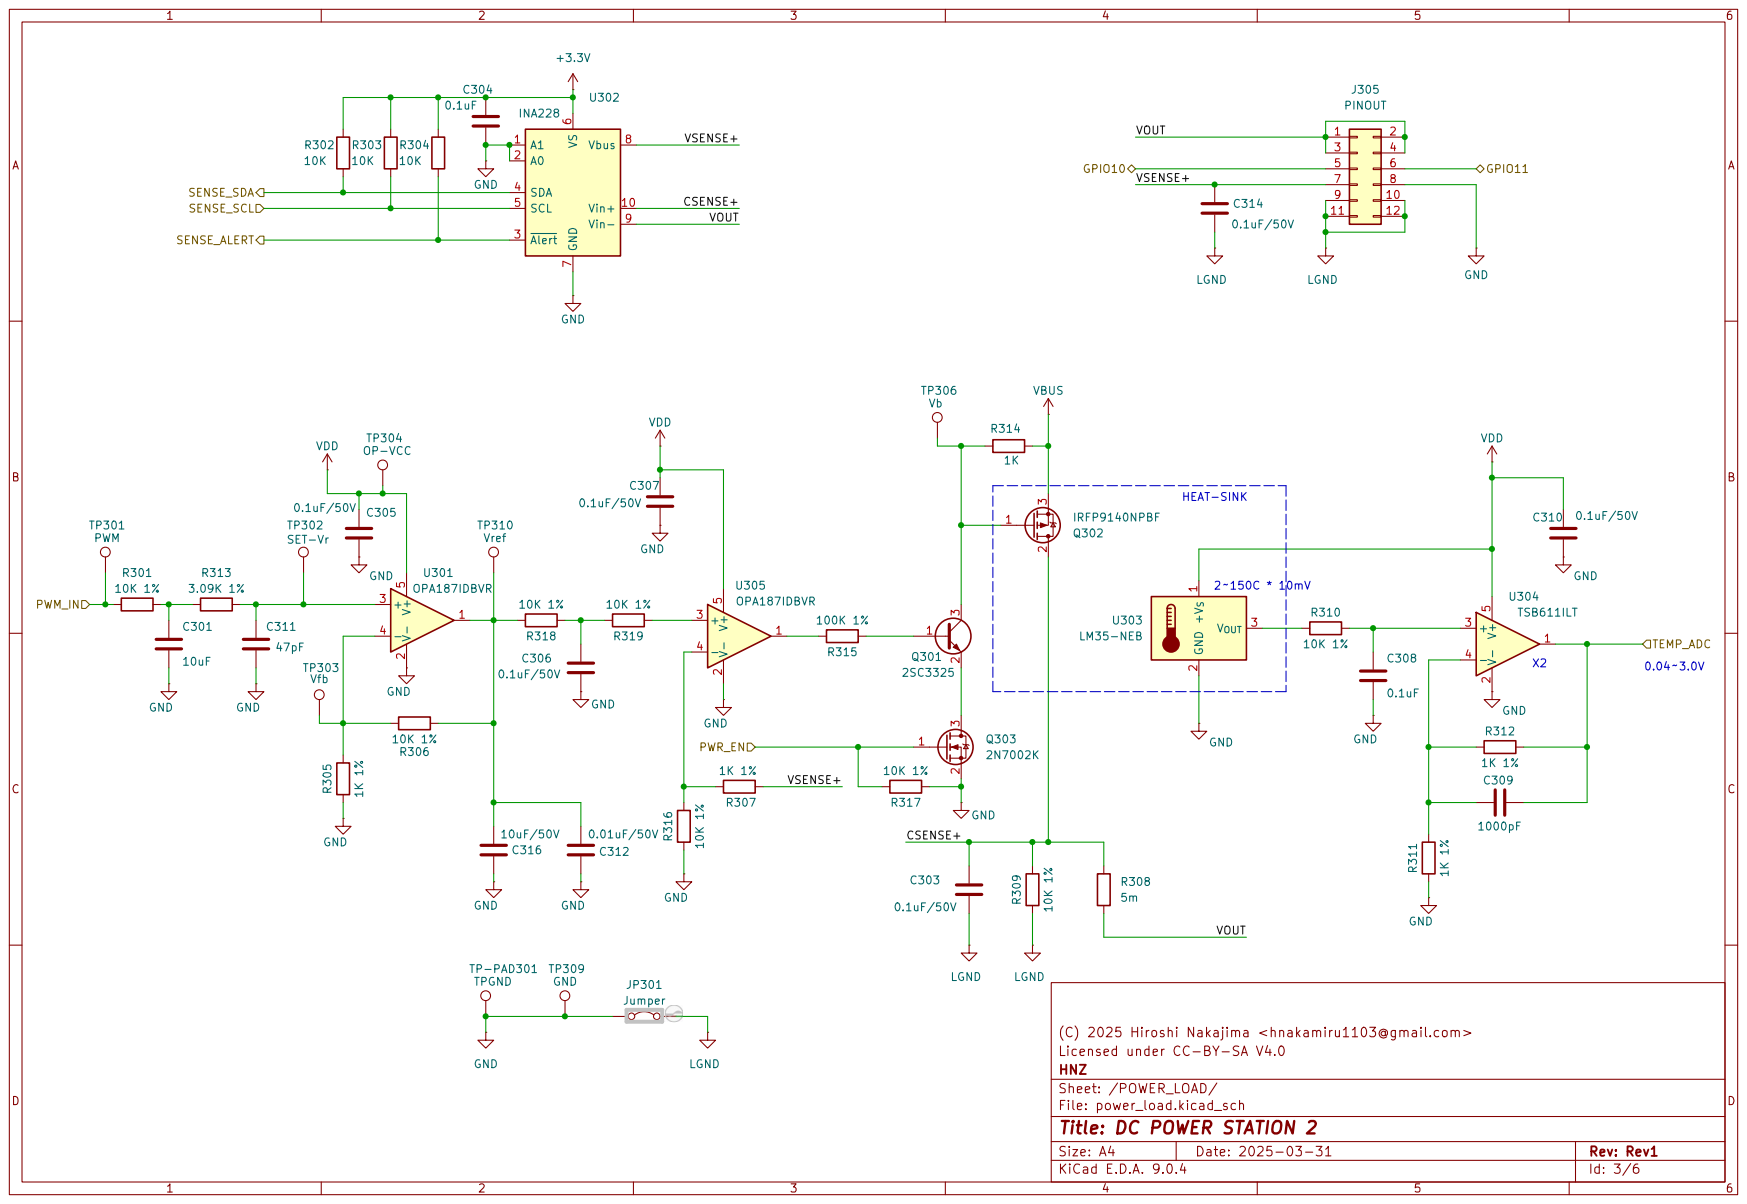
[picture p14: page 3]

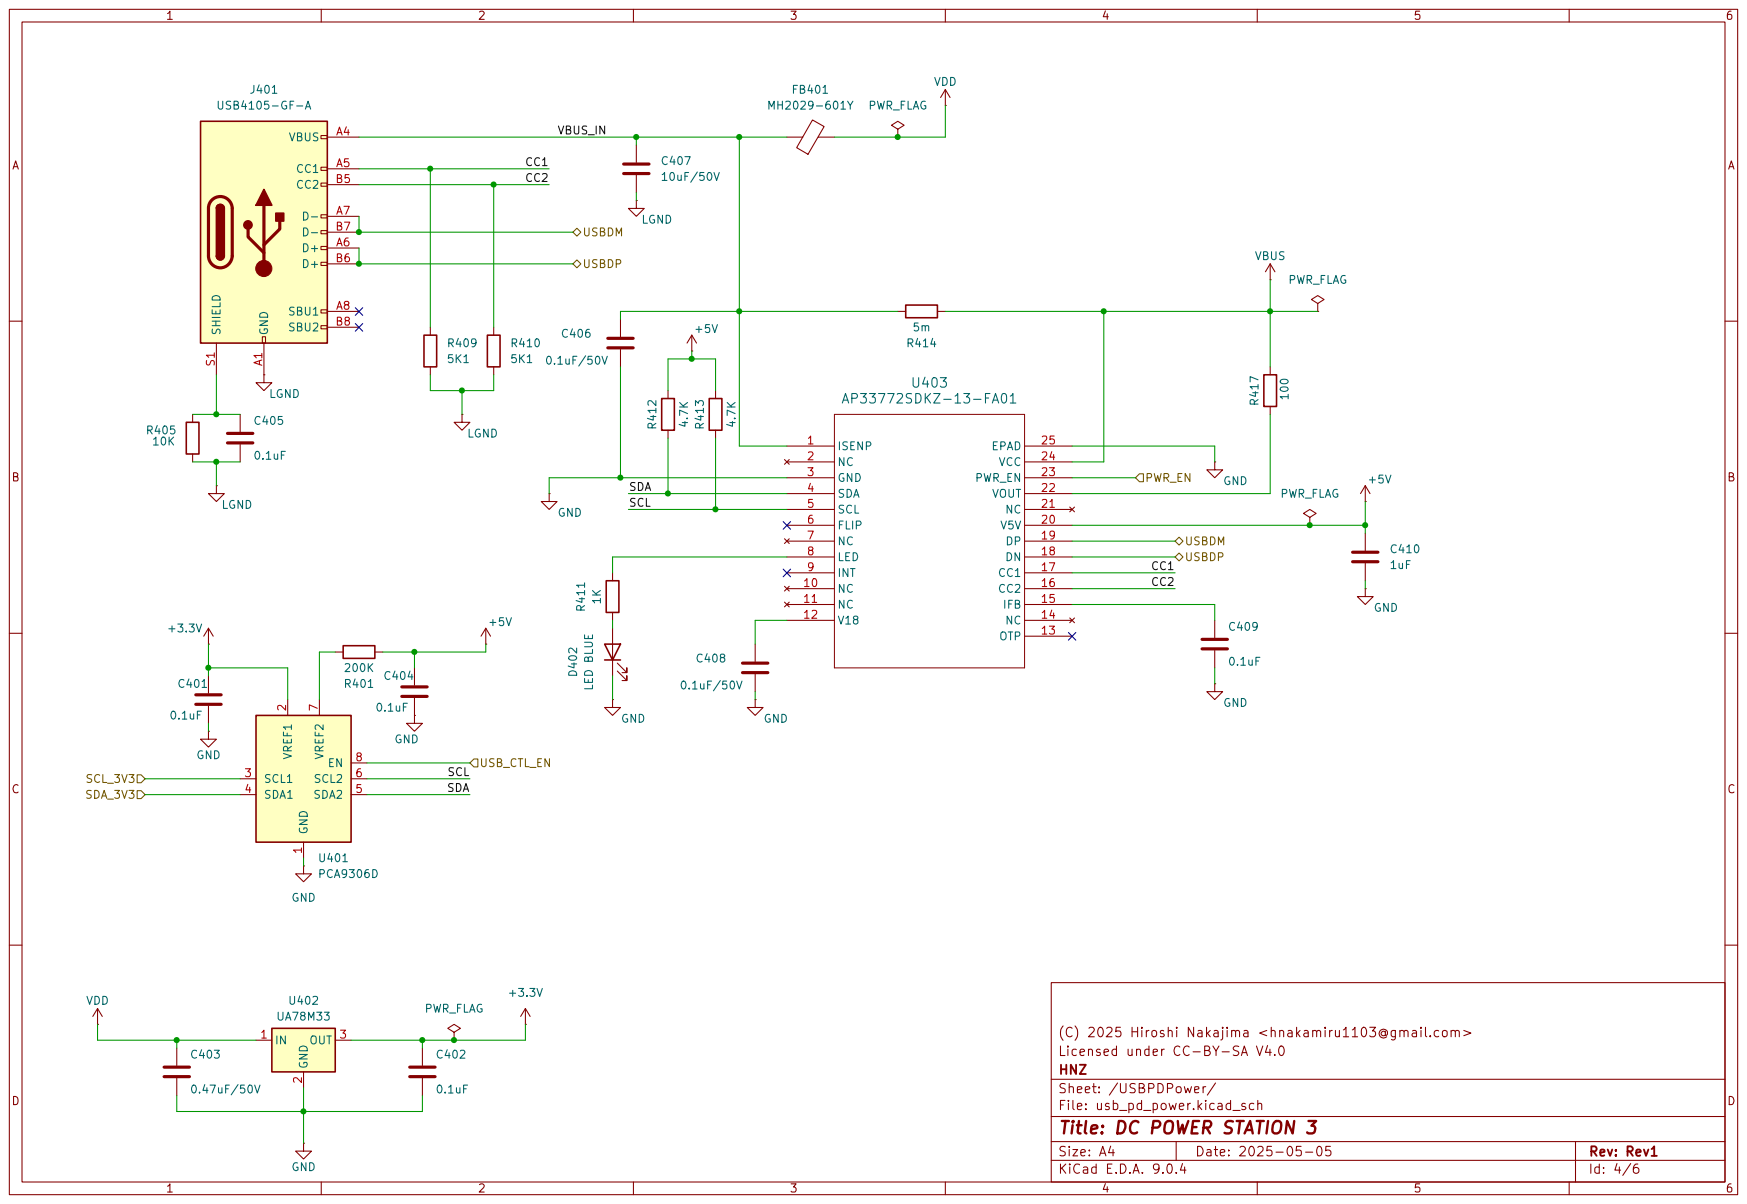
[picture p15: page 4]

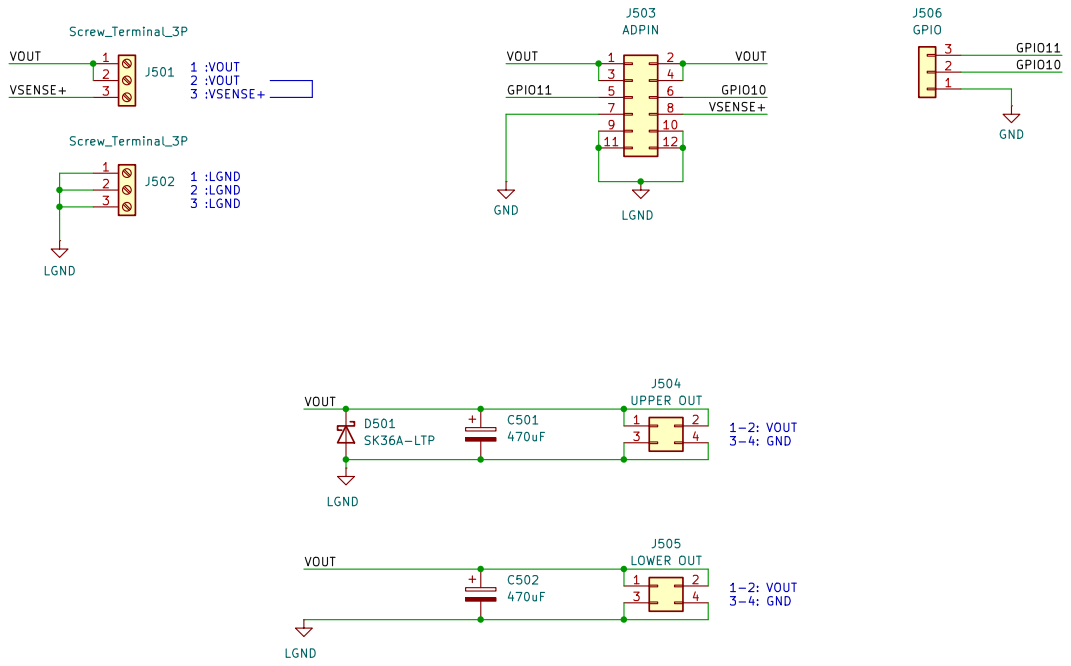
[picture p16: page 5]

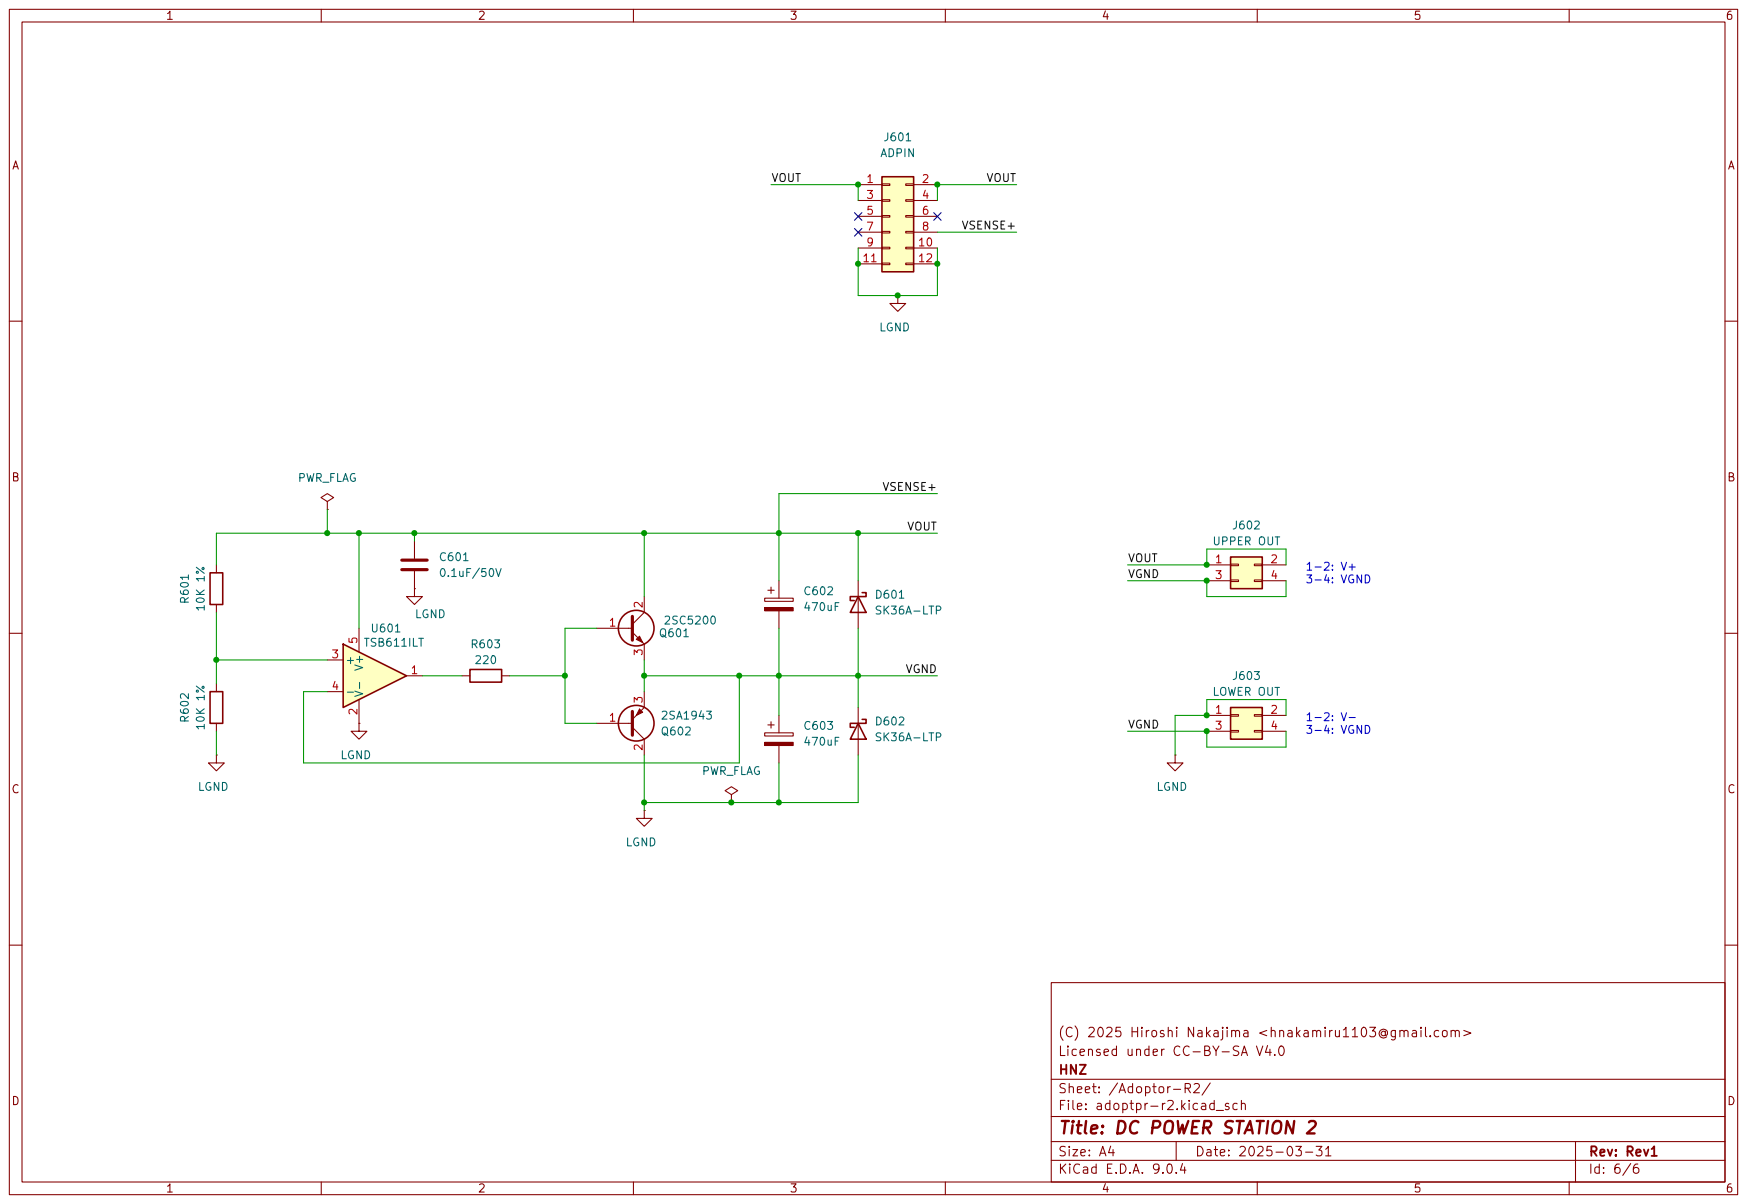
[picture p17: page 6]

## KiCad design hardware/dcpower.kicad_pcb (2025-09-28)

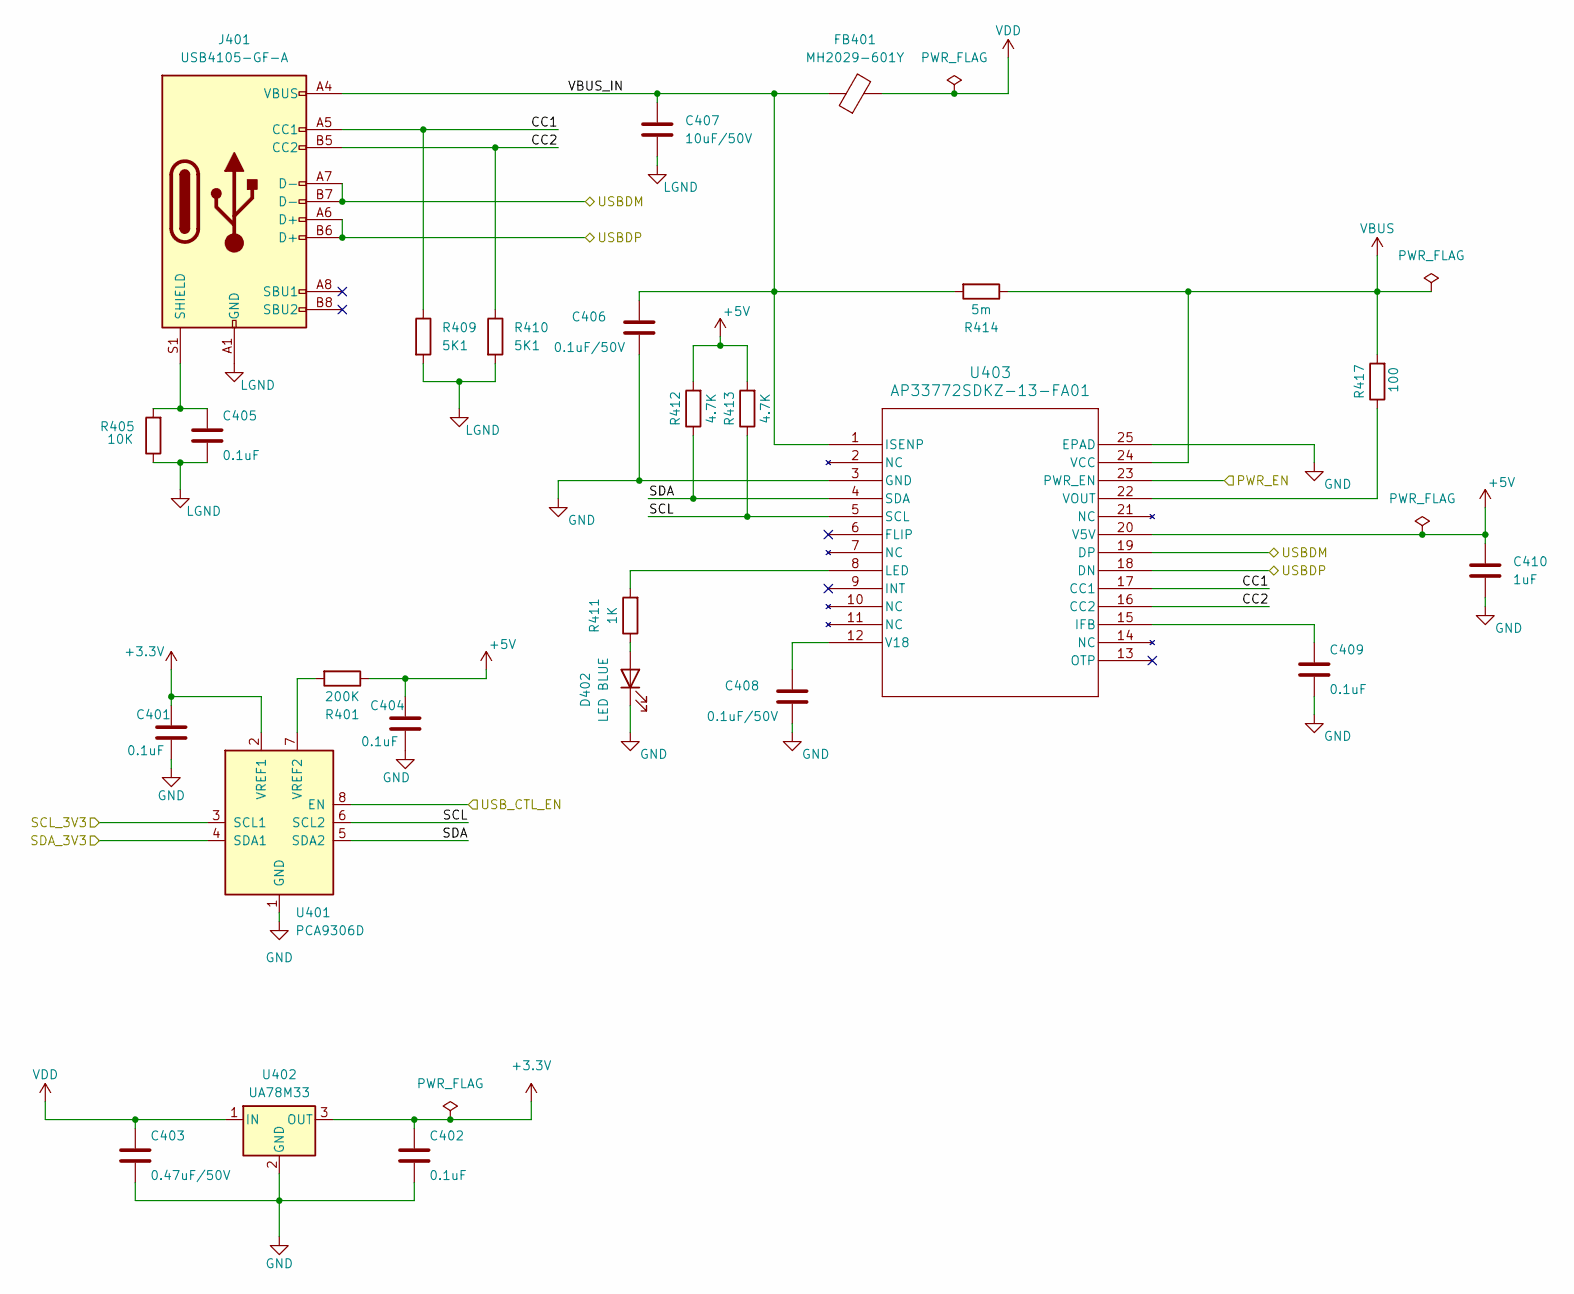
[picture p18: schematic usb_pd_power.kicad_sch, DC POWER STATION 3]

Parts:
C401, C402, C404, C405, C409: 0.1uF; C_0603_1608Metric; digikey 311-1343-1-ND
C403: 0.47uF/50V; C_0603_1608Metric; digikey 587-3170-1-ND
C406, C408: 0.1uF/50V; C_0603_1608Metric; digikey 311-1343-1-ND
C407: 10uF/50V; C_0805_2012Metric; digikey 490-18663-1-ND
C410: 1uF; C_0805_2012Metric; digikey 311-1365-1-ND
D402: LED BLUE; LED_0603_1608Metric; digikey 3147-B1931NB--20C007614U1930CT-ND
FB401: MH2029-601Y; L_0805_2012Metric; digikey MH2029-601YCT-ND
J401: USB4105-GF-A; USB_C_5077CR-16-SMC2-BK-TR; digikey 2073-USB4105-GF-ACT-ND
R401: 200K; R_0603_1608Metric; digikey 311-200KHRCT-ND
R405: 10K; R_0603_1608Metric; digikey 13-RC0603JR-1010KLCT-ND
R409, R410: 5K1; R_0603_1608Metric; digikey 311-5.10KHRCT-ND
R411: 1K; R_0603_1608Metric; digikey 13-RC0603JR-1010KLCT-ND
R412, R413: 4.7K; R_0603_1608Metric; digikey 311-4.70KHRCT-ND
R414: 5m; R_2512_6332Metric_Pad1.40x3.35mm_HandSolder; digikey 4506-PEWF2512D5L00Q9CT-ND
R417: 100; R_0603_1608Metric; digikey 311-100GRCT-ND
U401: PCA9306D; SSOP-8_2.95x2.8mm_P0.65mm; digikey 568-4215-1-ND
U402: UA78M33; TO-220-3_Horizontal_TabUp; digikey 296-13424-1-ND
U403: AP33772SDKZ-13-FA01; W-QFN4040-24_Type_A1_DIO; digikey 31-AP33772SDKZ-13-FA01CT-ND

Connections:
+3.3V: C401.1, C402.1, U401.2 (VREF1), U402.3 (OUT); also elsewhere on the board
+5V: C404.1, C410.1, R401.1, R412.2, R413.2, U403.20 (V5V)
/ESP32_CONT/IO21: U401.4 (SDA1); also elsewhere on the board
/ESP32_CONT/IO46: U401.8 (EN); also elsewhere on the board
/ESP32_CONT/SENSE_SCL: U401.3 (SCL1); also elsewhere on the board
/ESP32_CONT/USBDM: J401.A7 (D-), J401.B7 (D-), U403.19 (DP); also elsewhere on the board
/ESP32_CONT/USBDP: J401.A6 (D+), J401.B6 (D+), U403.18 (DN); also elsewhere on the board
/POWER_LOAD/PWR_EN: U403.23 (PWR_EN); also elsewhere on the board
/USBPDPower/CC1: J401.A5 (CC1), R409.1, U403.17 (CC1)
/USBPDPower/CC2: J401.B5 (CC2), R410.1, U403.16 (CC2)
/USBPDPower/SCL: R413.1, U401.6 (SCL2), U403.5 (SCL)
/USBPDPower/SDA: R412.1, U401.5 (SDA2), U403.4 (SDA)
/USBPDPower/VBUS_IN: C406.1, C407.1, FB401.1, J401.A4 (VBUS), J401.A9 (VBUS), J401.B4 (VBUS), J401.B9 (VBUS), R414.2, U403.1 (ISENP)
GND: C401.2, C402.2, C403.2, C404.2, C406.2, C408.2, C409.2, C410.2, D402.1 (K), U401.1 (GND), U402.2 (GND), U403.3 (GND), U403.25 (EPAD); also elsewhere on the board
LGND: C405.2, C407.2, J401.A1 (GND), J401.A12 (GND), J401.B1 (GND), J401.B12 (GND), R405.1, R409.2, R410.2; also elsewhere on the board
unnamed: D402.2 (A), R411.1
unnamed: C405.1, J401.S1 (SHIELD), R405.2
unnamed: R401.2, U401.7 (VREF2)
unnamed: C409.1, U403.15 (IFB)
unnamed: R411.2, U403.8 (LED)
unnamed: C408.1, U403.12 (V18)
unnamed: R417.1, U403.22 (VOUT)
VBUS: R414.1, R417.2, U403.24 (VCC); also elsewhere on the board
VDD: C403.1, FB401.2, U402.1 (IN); also elsewhere on the board

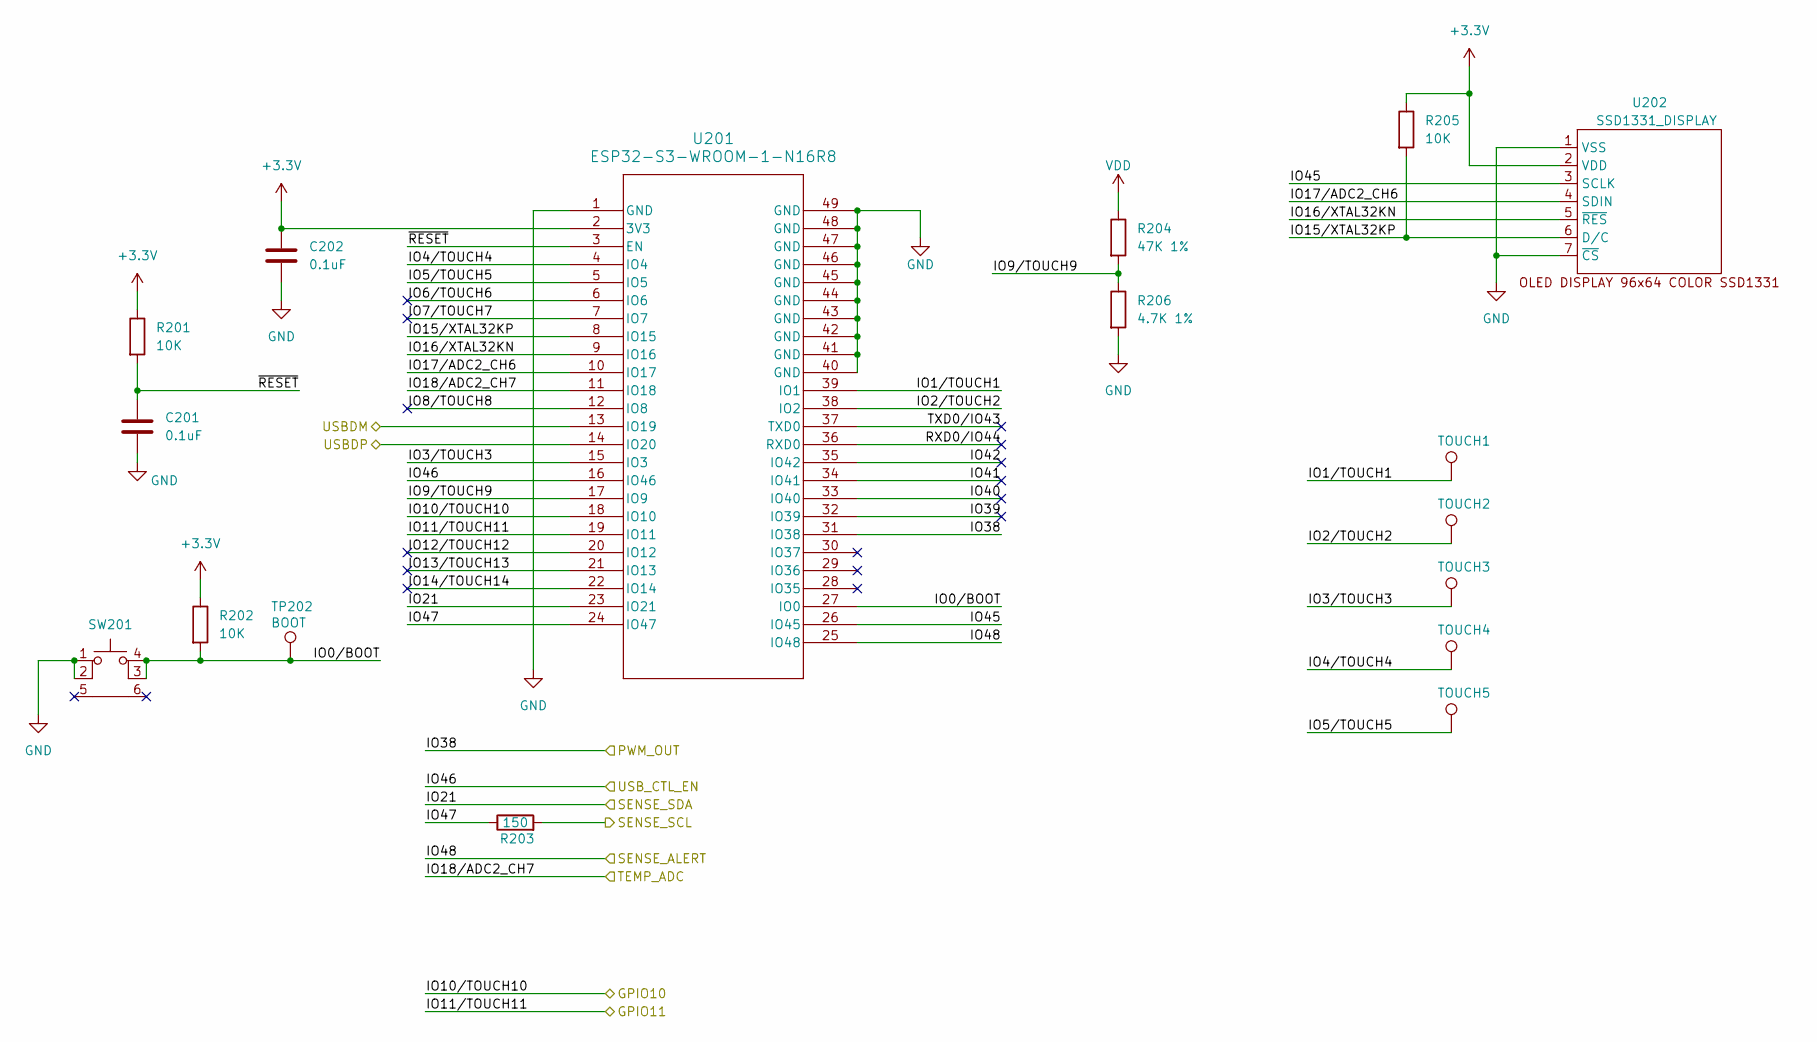
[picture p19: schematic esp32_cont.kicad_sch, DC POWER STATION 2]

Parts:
C201, C202: 0.1uF; C_0603_1608Metric; digikey 311-1343-1-ND
R201, R202, R205: 10K; R_0603_1608Metric; digikey 13-RC0603JR-1010KLCT-ND
R203: 150; R_0603_1608Metric; digikey 311-150GRCT-ND
R204: 47K 1%; R_0603_1608Metric; digikey 311-47.0KHRCT-ND
R206: 4.7K 1%; R_0603_1608Metric; digikey 311-4.70KHRCT-ND
SW201: 3.5x2.6 Tact SW; WS-TASV SMT Tact Switch; digikey 732-435151014824CT-ND
TP202: BOOT; TestPoint_Pad_D1.0mm
TP-PAD201: TOUCH1; TestPoint_Pad_3.2x1.6mm
TP-PAD202: TOUCH2; TestPoint_Pad_3.2x1.6mm
TP-PAD203: TOUCH3; TestPoint_Pad_3.2x1.6mm
TP-PAD204: TOUCH4; TestPoint_Pad_3.2x1.6mm
TP-PAD205: TOUCH5; TestPoint_Pad_3.2x1.6mm
U201: ESP32-S3-WROOM-1-N16R8; ESP32-S3-WROOM-1_EXP; digikey 1965-ESP32-S3-WROOM-1-N16R8CT-ND
U202: SSD1331_DISPLAY; OLED SSD1331 SPI DISPLAY; digikey 3190-DLC0095ANOB-1-ND

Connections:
+3.3V: C202.1, R201.1, R202.1, R205.1, U201.2 (3V3), U202.2 (VDD); also elsewhere on the board
/ESP32_CONT/IO0/BOOT: R202.2, SW201.3 (K), SW201.4 (A), TP202.1, U201.27 (IO0)
/ESP32_CONT/IO1/TOUCH1: TP-PAD201.1, U201.39 (IO1)
/ESP32_CONT/IO2/TOUCH2: TP-PAD202.1, U201.38 (IO2)
/ESP32_CONT/IO3/TOUCH3: TP-PAD203.1, U201.15 (IO3)
/ESP32_CONT/IO4/TOUCH4: TP-PAD204.1, U201.4 (IO4)
/ESP32_CONT/IO5/TOUCH5: TP-PAD205.1, U201.5 (IO5)
/ESP32_CONT/IO6/TOUCH6: U201.6 (IO6)
/ESP32_CONT/IO7/TOUCH7: U201.7 (IO7)
/ESP32_CONT/IO8/TOUCH8: U201.12 (IO8)
/ESP32_CONT/IO9/TOUCH9: R204.2, R206.1, U201.17 (IO9)
/ESP32_CONT/IO10/TOUCH10: U201.18 (IO10); also elsewhere on the board
/ESP32_CONT/IO11/TOUCH11: U201.19 (IO11); also elsewhere on the board
/ESP32_CONT/IO12/TOUCH12: U201.20 (IO12)
/ESP32_CONT/IO13/TOUCH13: U201.21 (IO13)
/ESP32_CONT/IO14/TOUCH14: U201.22 (IO14)
/ESP32_CONT/IO15/XTAL32KP: R205.2, U201.8 (IO15), U202.6 (D/C)
/ESP32_CONT/IO16/XTAL32KN: U201.9 (IO16), U202.5 (~RES)
/ESP32_CONT/IO17/ADC2_CH6: U201.10 (IO17), U202.4 (SDIN)
/ESP32_CONT/IO18/ADC2_CH7: U201.11 (IO18); also elsewhere on the board
/ESP32_CONT/IO21: U201.23 (IO21); also elsewhere on the board
/ESP32_CONT/IO38: U201.31 (IO38); also elsewhere on the board
/ESP32_CONT/IO39: U201.32 (IO39)
/ESP32_CONT/IO40: U201.33 (IO40)
/ESP32_CONT/IO41: U201.34 (IO41)
/ESP32_CONT/IO42: U201.35 (IO42)
/ESP32_CONT/IO45: U201.26 (IO45), U202.3 (SCLK)
/ESP32_CONT/IO46: U201.16 (IO46); also elsewhere on the board
/ESP32_CONT/IO47: R203.1, U201.24 (IO47)
/ESP32_CONT/IO48: U201.25 (IO48); also elsewhere on the board
/ESP32_CONT/RXD0/IO44: U201.36 (RXD0)
/ESP32_CONT/SENSE_SCL: R203.2; also elsewhere on the board
/ESP32_CONT/TXD0/IO43: U201.37 (TXD0)
/ESP32_CONT/USBDM: U201.13 (IO19); also elsewhere on the board
/ESP32_CONT/USBDP: U201.14 (IO20); also elsewhere on the board
/ESP32_CONT/~RESET: C201.1, R201.2, U201.3 (EN)
GND: C201.2, C202.2, R206.2, SW201.1, SW201.2, U201.1 (GND), U201.40 (GND), U201.41 (GND), U201.42 (GND), U201.43 (GND), U201.44 (GND), U201.45 (GND), U201.46 (GND), U201.47 (GND), U201.48 (GND), U201.49 (GND), U202.1 (VSS), U202.7 (~CS); also elsewhere on the board
VDD: R204.1; also elsewhere on the board

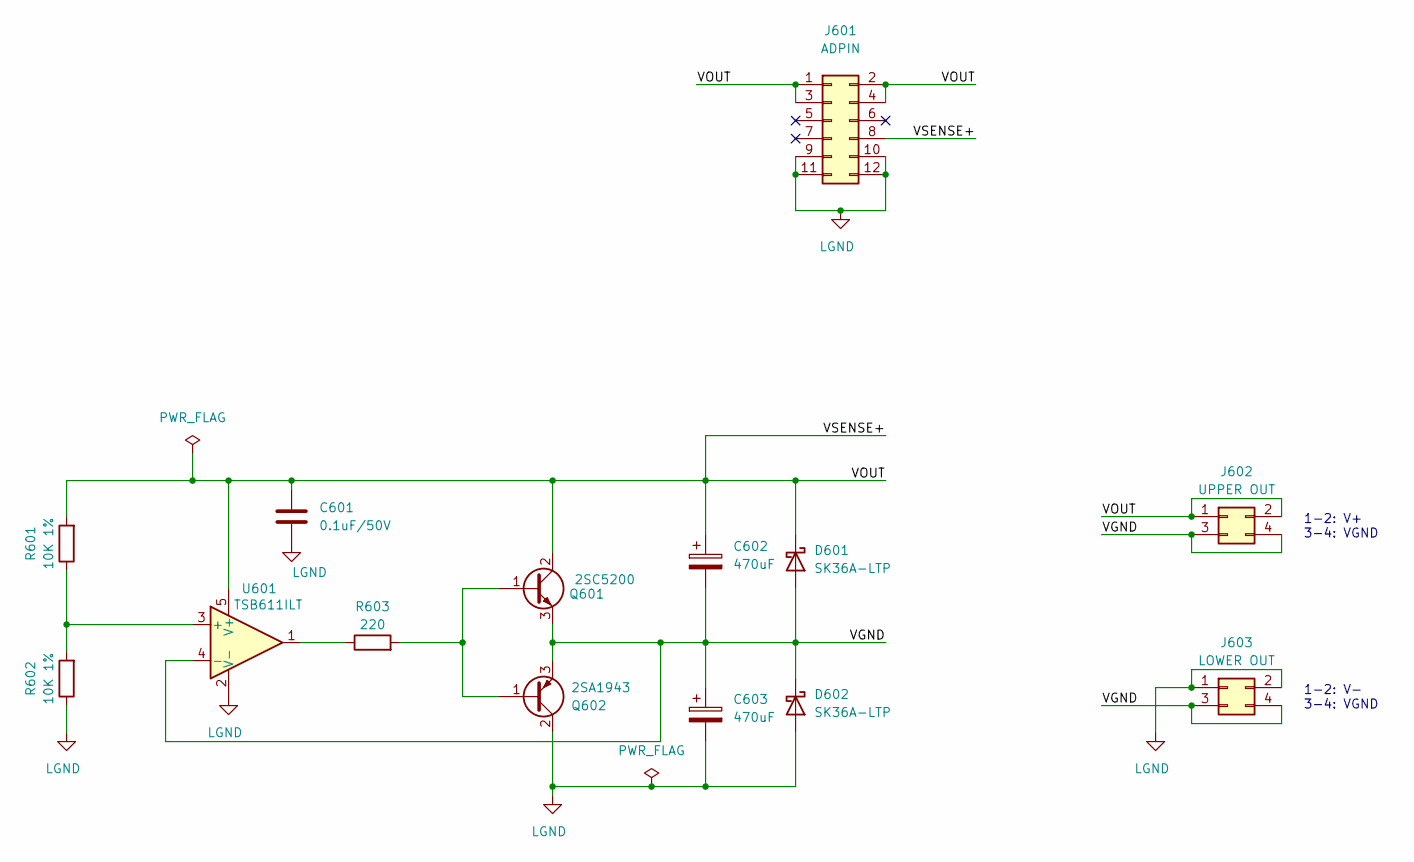
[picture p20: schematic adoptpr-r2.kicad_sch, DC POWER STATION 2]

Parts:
C601: 0.1uF/50V; C_0603_1608Metric; digikey 311-1343-1-ND
C602, C603: 470uF; CP_Radial_D8.0mm_P5.00mm; digikey 1189-1890-ND
D601, D602: SK36A-LTP; D_SMA; digikey SK36A-LTPMSCT-ND
J601: ADPIN; PinHeader_2x06_P2.54mm_Vertical; digikey 2057-PH2RA-12-UA-ND
J602: UPPER OUT; PinHeader_2x02_P2.54mm_Vertical; digikey 2057-PH2-04-UA-ND
J603: LOWER OUT; PinHeader_2x02_P2.54mm_Vertical; digikey 2057-PH2-04-UA-ND
Q601: 2SC5200; TO-3P-3_Horizontal_TabDown; digikey 5272-2SC5200-ND
Q602: 2SA1943; TO-3P-3_Horizontal_TabDown; digikey 5272-2SA1943-ND
R601, R602: 10K 1%; R_0603_1608Metric; digikey 311-10.0KHRCT-ND
R603: 220; R_0603_1608Metric; digikey 311-220GRCT-ND
U601: TSB611ILT; SOT-23-5; digikey 497-16082-1-ND

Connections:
/Adoptor-R2/VGND: C602.2, C603.1, D601.2 (A), D602.1 (K), J602.3, J602.4, J603.3, J603.4, Q601.3 (E), Q602.3 (E), U601.4 (-)
/Adoptor-R2/VOUT: C601.1, C602.1, D601.1 (K), J601.1, J601.2, J601.3, J601.4, J601.8, J602.1, J602.2, Q601.2 (C), R601.2, U601.5 (V+)
LGND: C601.2, C603.2, D602.2 (A), J601.9, J601.10, J601.11, J601.12, J603.1, J603.2, Q602.2 (C), R602.1, U601.2 (V-); also elsewhere on the board
unnamed: Q601.1 (B), Q602.1 (B), R603.2
unnamed: R603.1, U601.1
unnamed: R601.1, R602.2, U601.3 (+)

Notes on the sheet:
1-2: V+ 3-4: VGND
1-2: V- 3-4: VGND

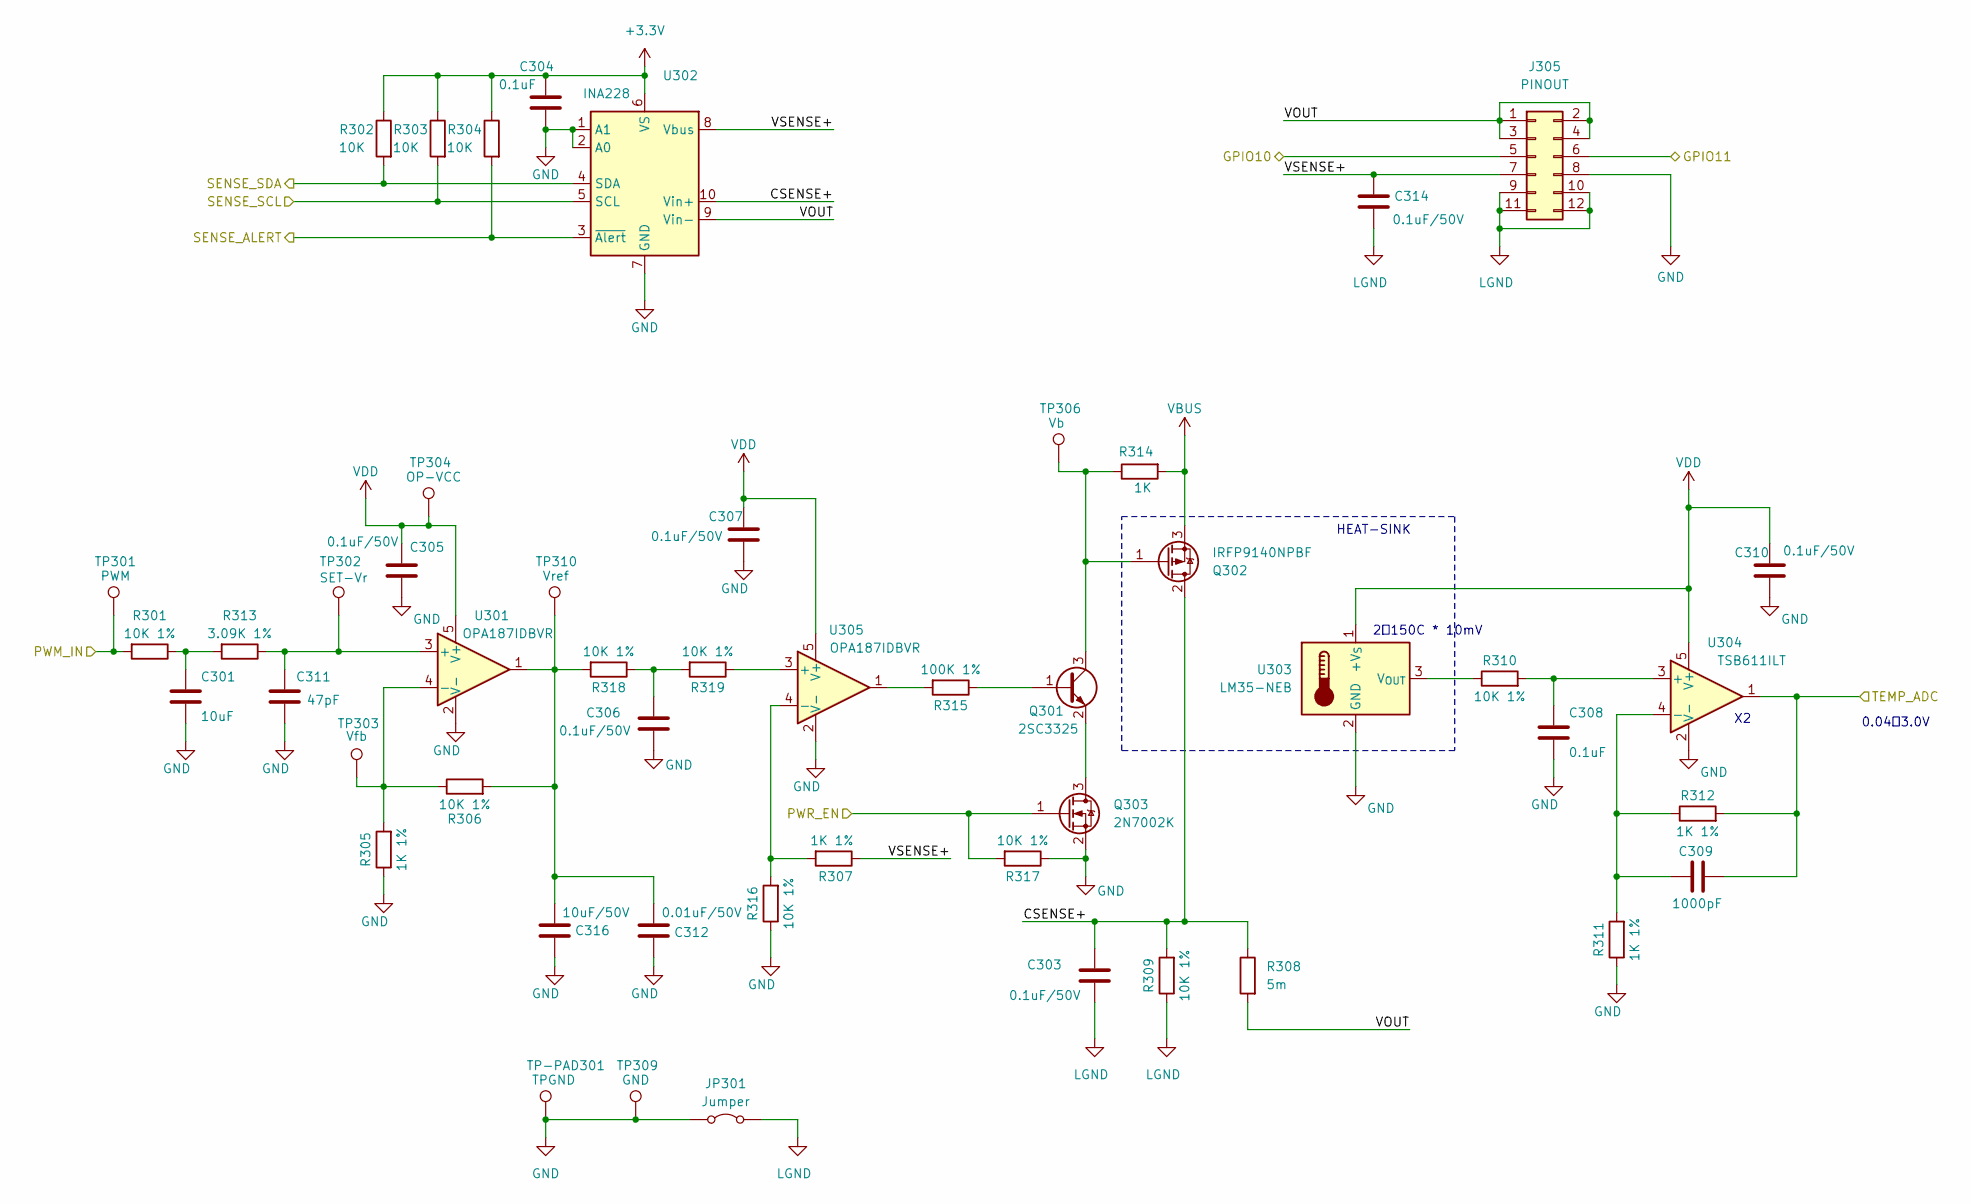
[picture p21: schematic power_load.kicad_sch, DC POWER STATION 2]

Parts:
C301: 10uF; C_0805_2012Metric; digikey 490-6473-1-ND
C303, C305, C306, C307, C310, C314: 0.1uF/50V; C_0603_1608Metric; digikey 311-1343-1-ND
C304, C308: 0.1uF; C_0603_1608Metric; digikey 311-1343-1-ND
C309: 1000pF; C_0603_1608Metric; digikey 311-1080-1-ND
C311: 47pF; C_0603_1608Metric; digikey 311-3980-1-ND
C312: 0.01uF/50V; C_0603_1608Metric; digikey 311-1085-1-ND
C316: 10uF/50V; C_0805_2012Metric; digikey 490-18663-1-ND
J305: PINOUT; PinHeader_2x06_P2.54mm_Vertical; digikey PPPC062LJBN-RC
JP301: Jumper; SolderJumper-2_P1.3mm_Bridged_RoundedPad1.0x1.5mm
Q301: 2SC3325; SC-59; digikey 2SC3325-YLFCT-ND
Q302: IRFP9140NPBF; TO-247-3_Horizontal_TabUp; digikey IRFP9140NPBF-ND
Q303: 2N7002K; SOT-23; digikey 2N7002KCT-ND
R301, R306, R309, R310, R316, R317, R318, R319: 10K 1%; R_0603_1608Metric; digikey 311-10.0KHRCT-ND
R302, R303, R304: 10K; R_0603_1608Metric; digikey 13-RC0603JR-1010KLCT-ND
R305, R307, R311, R312: 1K 1%; R_0603_1608Metric; digikey YAG2323CT-ND
R308: 5m; R_2512_6332Metric_Pad1.40x3.35mm_HandSolder; digikey 4506-PEWF2512D5L00Q9CT-ND
R313: 3.09K 1%; R_0603_1608Metric; digikey 311-3.09KHRCT-ND
R314: 1K; R_0603_1608Metric; digikey 13-RC0603JR-1010KLCT-ND
R315: 100K 1%; R_0603_1608Metric; digikey 311-100KHRCT-ND
TP301: PWM; TestPoint_Pad_D1.0mm
TP302: SET-Vr; TestPoint_Pad_D1.0mm
TP303: Vfb; TestPoint_Pad_D1.0mm
TP304: OP-VCC; TestPoint_Pad_D1.0mm
TP306: Vb; TestPoint_Pad_D1.0mm
TP309: GND; TestPoint_Pad_D1.0mm
TP310: Vref; TestPoint_Pad_D1.0mm
TP-PAD301: TPGND; TestPoint_Pad_3.2x1.6mm; digikey 2019-RCWCTECT-ND
U301, U305: OPA187IDBVR; SOT-23-5; digikey 296-53156-1-ND
U302: INA228; VSSOP-10_3x3mm_P0.5mm; digikey 296-INA228AIDGSRCT-ND
U303: LM35-NEB; TO-220-3_Horizontal_TabDown; digikey LM35DT/NOPB-ND
U304: TSB611ILT; SOT-23-5; digikey 497-16082-1-ND

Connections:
+3.3V: C304.1, R302.1, R303.1, R304.1, U302.6 (VS); also elsewhere on the board
/ESP32_CONT/IO10/TOUCH10: J305.5; also elsewhere on the board
/ESP32_CONT/IO11/TOUCH11: J305.6; also elsewhere on the board
/ESP32_CONT/IO18/ADC2_CH7: C309.2, R312.2, U304.1; also elsewhere on the board
/ESP32_CONT/IO21: R302.2, U302.4 (SDA); also elsewhere on the board
/ESP32_CONT/IO38: R301.2, TP301.1; also elsewhere on the board
/ESP32_CONT/IO48: R304.2, U302.3 (~Alert); also elsewhere on the board
/ESP32_CONT/SENSE_SCL: R303.2, U302.5 (SCL); also elsewhere on the board
/POWER_LOAD/CSENSE+: C303.1, Q302.2 (D), R308.1, R309.2, U302.10 (Vin+)
/POWER_LOAD/PWR_EN: Q303.1 (G), R317.2; also elsewhere on the board
/POWER_LOAD/VOUT: J305.1, J305.2, J305.3, J305.4, R308.2, U302.9 (Vin-)
/POWER_LOAD/VSENSE+: C314.1, J305.7, R307.1, U302.8 (Vbus)
GND: C301.2, C304.2, C305.2, C306.2, C307.2, C308.2, C310.2, C311.1, C312.2, C316.1, J305.8, JP301.1 (A), Q303.2 (S), R305.1, R311.1, R316.1, R317.1, TP309.1, TP-PAD301.1, U301.2 (V-), U302.1 (A1), U302.2 (A0), U302.7 (GND), U303.2 (GND), U304.2 (V-), U305.2 (V-); also elsewhere on the board
LGND: C303.2, C314.2, J305.9, J305.10, J305.11, J305.12, JP301.2 (B), R309.1; also elsewhere on the board
unnamed: C301.1, R301.1, R313.2
unnamed: C306.1, R318.1, R319.2
unnamed: C312.1, C316.2, R306.2, R318.2, TP310.1, U301.1
unnamed: Q301.1 (B), R315.1
unnamed: Q301.3 (C), Q302.1 (G), R314.1, TP306.1
unnamed: Q301.2 (E), Q303.3 (D)
unnamed: R315.2, U305.1
unnamed: C311.2, R313.1, TP302.1, U301.3 (+)
unnamed: R305.2, R306.1, TP303.1, U301.4 (-)
unnamed: R310.1, U303.3 (V_{OUT})
unnamed: C308.1, R310.2, U304.3 (+)
unnamed: C309.1, R311.2, R312.1, U304.4 (-)
unnamed: R319.1, U305.3 (+)
unnamed: R307.2, R316.2, U305.4 (-)
VBUS: Q302.3 (S), R314.2; also elsewhere on the board
VDD: C305.1, C307.1, C310.1, TP304.1, U301.5 (V+), U303.1 (+V_{S}), U304.5 (V+), U305.5 (V+); also elsewhere on the board

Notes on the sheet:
HEAT-SINK
2～150C * 10mV
0.04～3.0V

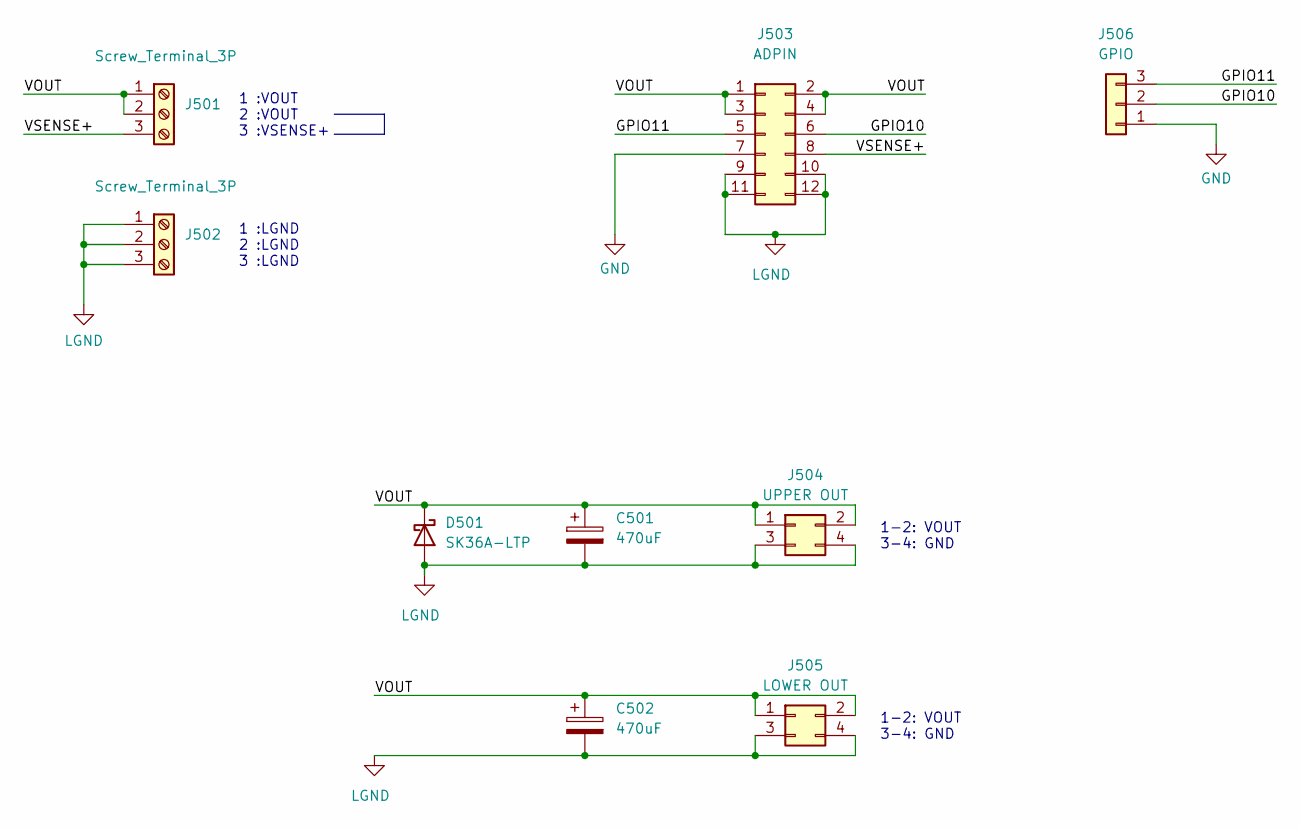
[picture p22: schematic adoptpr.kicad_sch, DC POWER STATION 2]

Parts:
C501, C502: 470uF; CP_Radial_D8.0mm_P5.00mm; digikey 1189-1890-ND
D501: SK36A-LTP; D_SMA; digikey SK36A-LTPMSCT-ND
J501, J502: Screw_Terminal_3P; TB112-2-2-3-E-1 Terminal Block; digikey A113321-ND
J503: ADPIN; PinHeader_2x06_P2.54mm_Vertical; digikey 2057-PH2RA-12-UA-ND
J504: UPPER OUT; PinHeader_2x02_P2.54mm_Vertical; digikey 2057-PH2-04-UA-ND
J505: LOWER OUT; PinHeader_2x02_P2.54mm_Vertical; digikey 2057-PH2-04-UA-ND
J506: GPIO; PinHeader_1x03_P2.54mm_Vertical; digikey 2057-RS1-03-G-ND

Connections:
/Adoptor-R1/GPIO10: J503.6, J506.2
/Adoptor-R1/GPIO11: J503.5, J506.3
/Adoptor-R1/VOUT: C501.1, C502.1, D501.1 (K), J501.1, J501.2, J503.1, J503.2, J503.3, J503.4, J504.1, J504.2, J505.1, J505.2
/Adoptor-R1/VSENSE+: J501.3, J503.8
GND: J503.7, J506.1; also elsewhere on the board
LGND: C501.2, C502.2, D501.2 (A), J502.1, J502.2, J502.3, J503.9, J503.10, J503.11, J503.12, J504.3, J504.4, J505.3, J505.4; also elsewhere on the board

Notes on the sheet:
1 :LGND 2 :LGND 3 :LGND
1-2: VOUT 3-4: GND
1 :VOUT 2 :VOUT 3 :VSENSE+

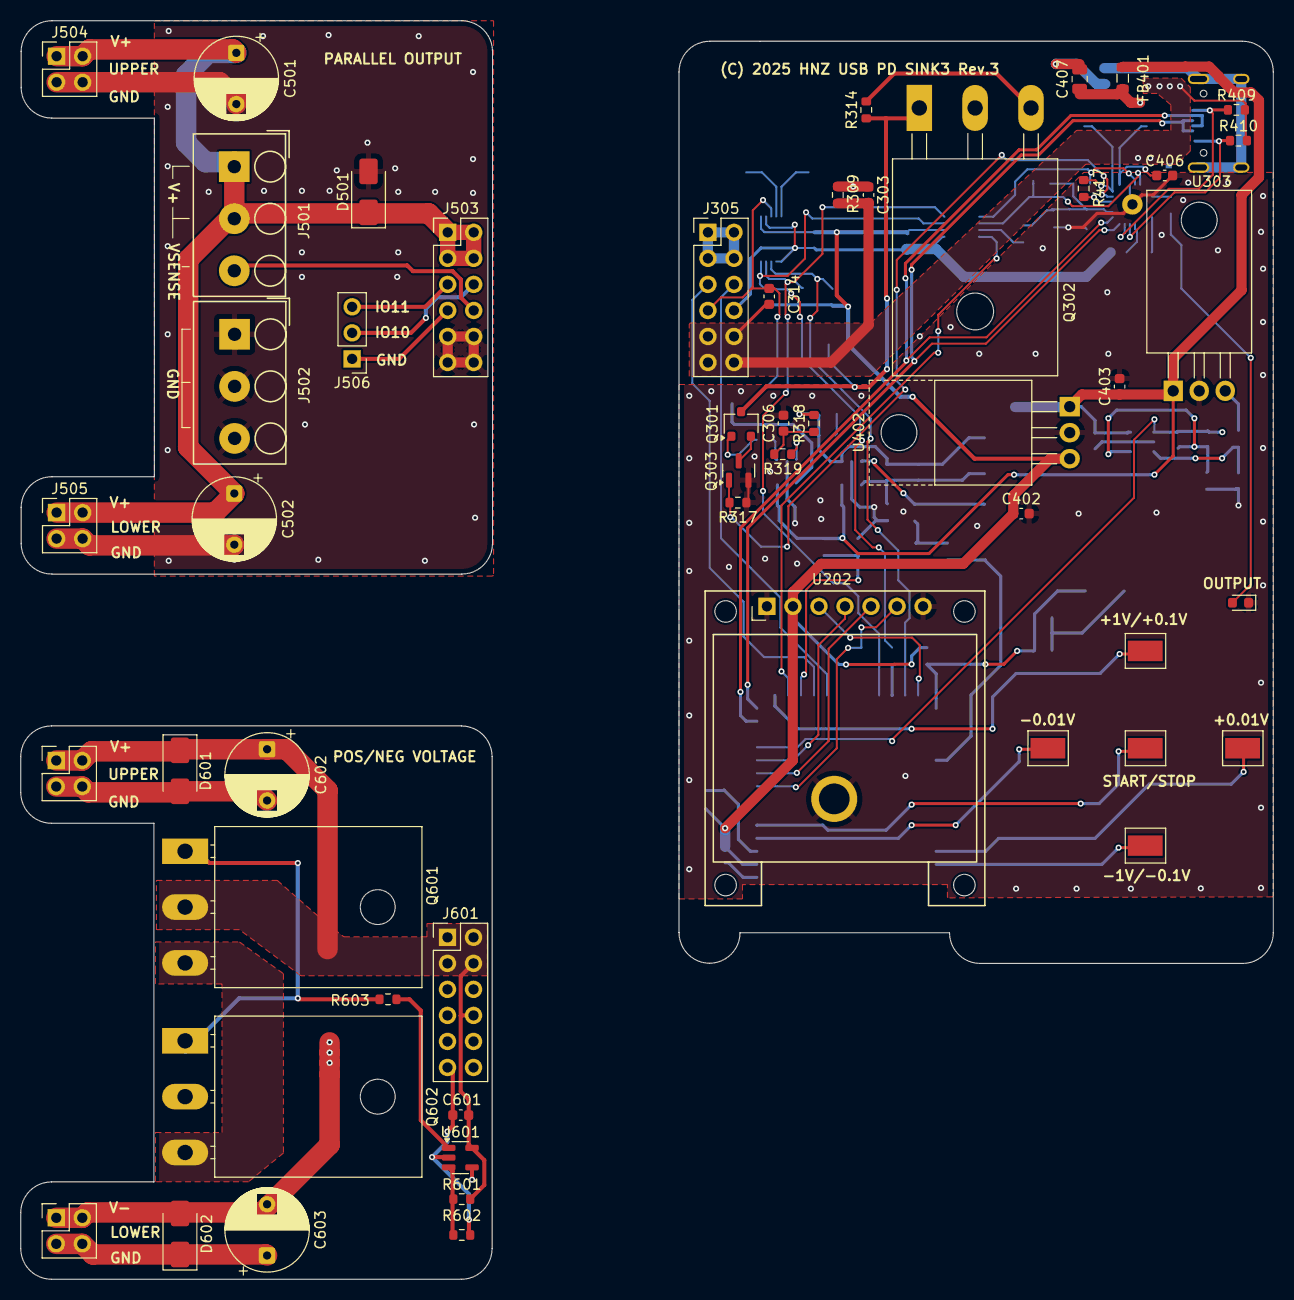
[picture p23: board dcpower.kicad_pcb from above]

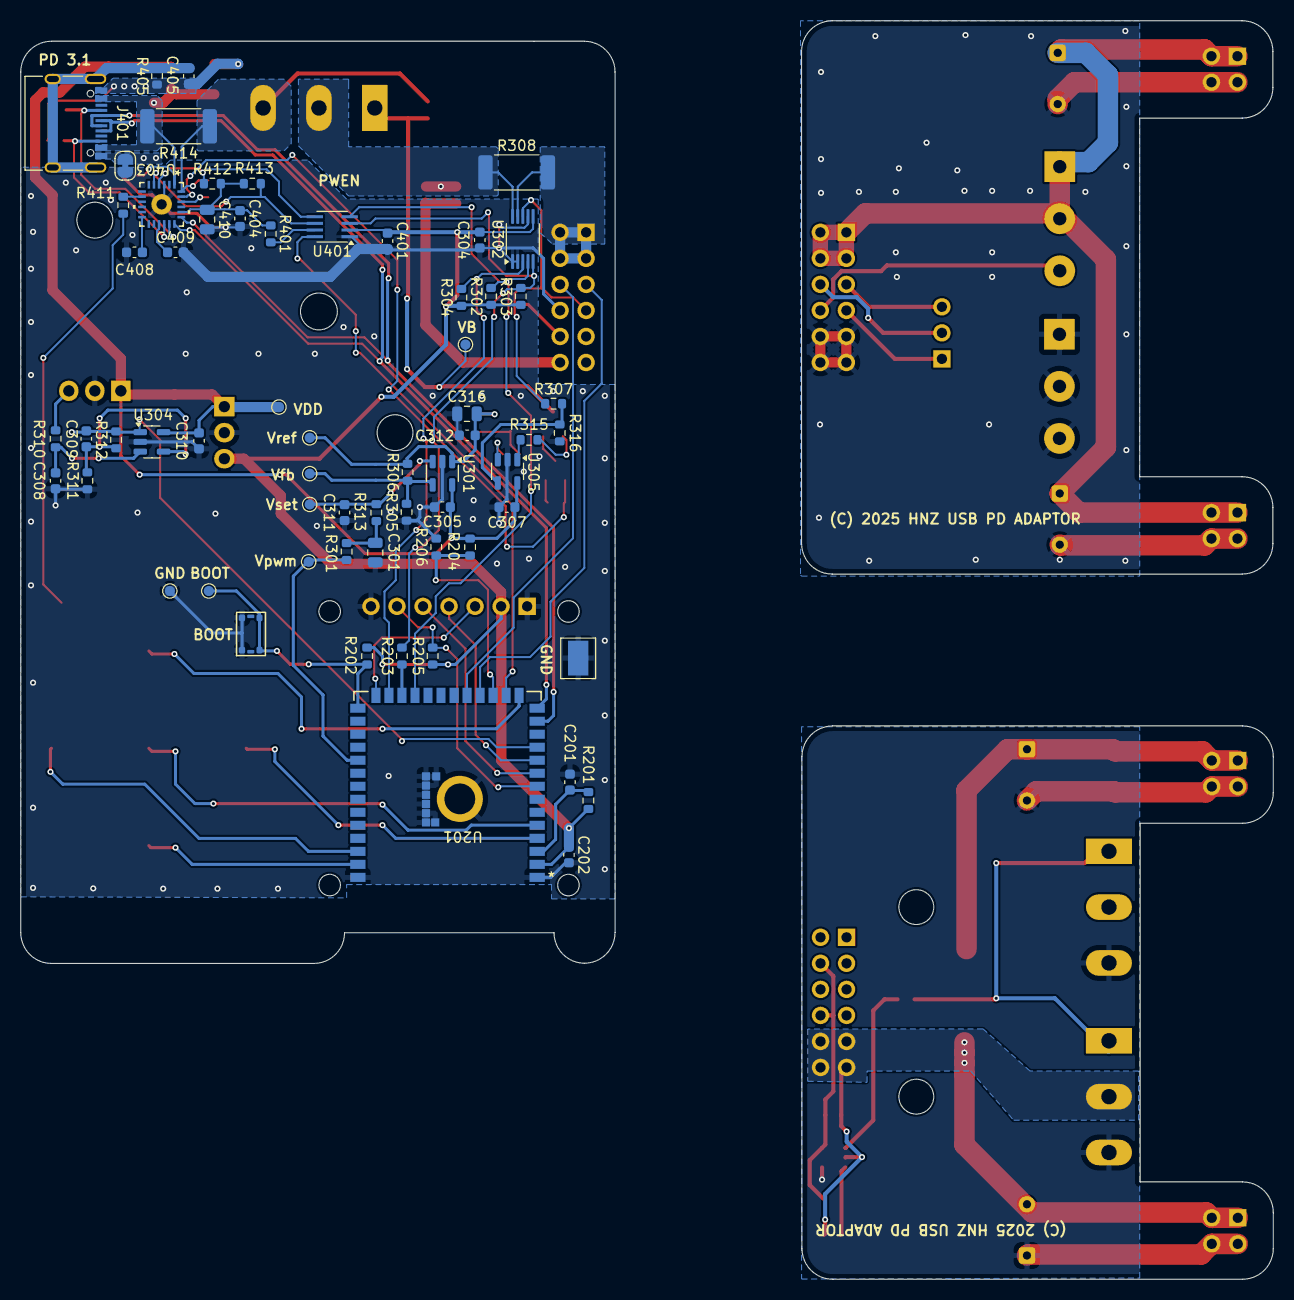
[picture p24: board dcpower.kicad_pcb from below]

Board: 2 copper layers, 58.0 x 90.0 mm, 115 parts (63 on the bottom side), 68 nets.

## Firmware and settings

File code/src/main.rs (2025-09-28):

// This is electric-load main program for ESP32-S3-WROOM-1-N16R8.
// SPDX-License-Identifier: MIT
// Copyright (c) 2025 Hiroshi Nakajima

use std::{thread, time::Duration};
use esp_idf_hal::{gpio::*, prelude::*, spi, i2c};
use esp_idf_hal::delay::BLOCK;
use esp_idf_hal::peripherals::Peripherals;
use embedded_hal::spi::MODE_0;
use log::*;
use std::time::SystemTime;
use esp_idf_hal::adc::oneshot::config::AdcChannelConfig as AdcConfig;
use esp_idf_hal::adc::oneshot::config::Calibration;
use esp_idf_hal::adc::oneshot::*;
use esp_idf_hal::adc::attenuation::DB_11;
use esp_idf_hal::ledc::config::TimerConfig;
use esp_idf_hal::ledc::LedcTimerDriver;
use esp_idf_hal::ledc::LedcDriver;
use esp_idf_svc::sntp::{EspSntp, SyncStatus, SntpConf, OperatingMode, SyncMode};
use esp_idf_svc::wifi::EspWifi;
use esp_idf_svc::nvs::*;
use chrono::{DateTime, Utc};

mod displayctl;
mod currentlogs;
mod wifi;
mod transfer;
mod touchpad;
mod pidcont;
mod usbpd;
mod syslogger;  // Add the syslogger module

use displayctl::{DisplayPanel, LoggingStatus, WifiStatus};
use currentlogs::{CurrentRecord, CurrentLog};
use transfer::{Transfer, ServerInfo};
use touchpad::{TouchPad, KeyEvent, Key};
use pidcont::PIDController;
use usbpd::{AP33772S, PDVoltage};

const ADCRANGE : bool = true; // true: 40.96mV, false: 163.84mV

#[toml_cfg::toml_config]
pub struct Config {
    #[default("")]
    wifi_ssid: &'static str,
    #[default("")]
    wifi_psk: &'static str,
    #[default("")]
    influxdb_server: &'static str,
    #[default("0.00001")]
    pid_kp: &'static str,
    #[default("0.05")]
    pid_ki: &'static str,
    #[default("0.000001")]
    pid_kd: &'static str,
    #[default("4500")]
    pwm_offset: &'static str,
    #[default("0.0")]
    pd_config_offset: &'static str,
    #[default("0.0")]
    shunt_resistance: &'static str,
    #[default("50")]
    shunt_temp_coefficient: &'static str,
    #[default("11.0")]
    max_current_limit: &'static str,
    #[default("110.0")]
    max_power_limit: &'static str,
    #[default("75.0")]
    max_temperature: &'static str,
    #[default("")]
    influxdb_api_key: &'static str,
    #[default("")]
    influxdb_api: &'static str,
    #[default("")]
    influxdb_measurement: &'static str,
    #[default("")]
    influxdb_tag: &'static str,
    #[default("")]
    syslog_server: &'static str,
    #[default("")]
    syslog_enable: &'static str,
}

// NVS key for storing the last voltage setting
const NVS_NAMESPACE: &str = "dcpowerunit";
const VOLTAGE_KEY: &str = "last_voltage";

// Function to save voltage setting to NVS
fn save_voltage_to_nvs(voltage: f32) -> anyhow::Result<()> {
    let nvs_default_partition = EspDefaultNvsPartition::take()?;
    let mut nvs = EspNvs::new(nvs_default_partition, NVS_NAMESPACE, true)?;
    
    // Convert f32 to bytes for storage
    let voltage_bytes = voltage.to_le_bytes();
    nvs.set_blob(VOLTAGE_KEY, &voltage_bytes)?;
    info!("Voltage {:.3}V saved to NVS", voltage);
    Ok(())
}

// Function to load voltage setting from NVS
fn load_voltage_from_nvs() -> anyhow::Result<f32> {
    let nvs_default_partition = EspDefaultNvsPartition::take()?;
    let nvs = EspNvs::new(nvs_default_partition, NVS_NAMESPACE, false)?;
    
    let mut voltage_bytes = [0u8; 4];
    match nvs.get_blob(VOLTAGE_KEY, &mut voltage_bytes) {
        Ok(Some(_)) => {
            let voltage = f32::from_le_bytes(voltage_bytes);
            info!("Voltage {:.3}V loaded from NVS", voltage);
            Ok(voltage)
        },
        Ok(None) => {
            info!("No voltage setting found in NVS, using default 0.0V");
            Ok(0.0)
        },
        Err(e) => {
            info!("Failed to read voltage from NVS: {:?}, using default 0.0V", e);
            Ok(0.0)
        }
    }
}

fn main() -> anyhow::Result<()> {
    esp_idf_sys::link_patches();
    
    // Initialize the default ESP logger only if syslog is disabled
    // If syslog is enabled, we'll initialize the syslog logger later
    if CONFIG.syslog_enable != "true" {
        esp_idf_svc::log::EspLogger::initialize_default();
        // Set log level to INFO to ensure info!() messages are displayed
        log::set_max_level(log::LevelFilter::Info);
    }
    
    // Peripherals Initialize
    let peripherals = Peripherals::take().unwrap();
    // Initialize nvs
    unsafe {
        esp_idf_sys::nvs_flash_init();
    }

    // Log startup message
    println!("DCPowerUnit2 application started (println)");
    info!("DCPowerUnit2 application started (info)");
    
    // Load Config
    let max_current_limit = CONFIG.max_current_limit.parse::<f32>().unwrap();
    let max_power_limit = CONFIG.max_power_limit.parse::<f32>().unwrap();
    let max_temperature = CONFIG.max_temperature.parse::<f32>().unwrap();
    println!("[Config Limit] Current: {}A  Power: {}W  Temperature: {}°C", max_current_limit, max_power_limit, max_temperature);
    info!("[Config Limit] Current: {}A  Power: {}W  Temperature: {}°C", max_current_limit, max_power_limit, max_temperature);
    let server_info = ServerInfo::new(CONFIG.influxdb_server.to_string(), 
        CONFIG.influxdb_api_key.to_string(),
        CONFIG.influxdb_api.to_string(),
        CONFIG.influxdb_measurement.to_string(),
        CONFIG.influxdb_tag.to_string());

    // Display SPI
    let spi = peripherals.spi2;
    let sclk = peripherals.pins.gpio45;
    let sdo  = peripherals.pins.gpio17;
    let sdi_not_used : Option<Gpio2> = None;
    let cs_not_used : Option<Gpio2> = None;
    let dc = PinDriver::output(peripherals.pins.gpio15)?;
    let rst = PinDriver::output(peripherals.pins.gpio16)?;
    let spi_config = spi::SpiConfig::new().baudrate(1.MHz().into()).data_mode(MODE_0);
    let spi_driver_config = spi::config::DriverConfig::new();

    let spi_driver = spi::SpiDriver::new(
        spi,
        sclk,
        sdo,
        sdi_not_used,
        &spi_driver_config
    ).unwrap();
    
    let spi_device = spi::SpiDeviceDriver::new(spi_driver, cs_not_used, &spi_config)?;
    let mut dp = DisplayPanel::new();
    dp.start(spi_device, dc, rst);

    // Current/Voltage
    let i2c = peripherals.i2c0;
    let scl = peripherals.pins.gpio47;
    let sda = peripherals.pins.gpio21;
    let config = i2c::I2cConfig::new().baudrate(400.kHz().into());
    let mut i2cdrv = i2c::I2cDriver::new(i2c, sda, scl, &config)?;

    // read config
    let mut i2c_sel = PinDriver::output(peripherals.pins.gpio46).unwrap();
    i2c_sel.set_high().unwrap(); // Enable USB PD
    let mut ap33772s = AP33772S::new();
    match ap33772s.init(&mut i2cdrv) {
        Ok(()) => {
            info!("AP33772S initialized successfully");
        },
        Err(e) => {
            return Err(anyhow::anyhow!("Failed to initialize AP33772S: {:?}", e));
        }
    }

    // Configure protection features: UVP=true, OVP=true, OCP=true, OTP=false, DR=false
    match ap33772s.configure_protections(&mut i2cdrv, true, true, true, false, false) {
        Ok(()) => {
            info!("AP33772S protections configured successfully");
        },
        Err(e) => {
            warn!("Failed to configure AP33772S protections: {:?}", e);
        }
    }
    match ap33772s.get_status(&mut i2cdrv) {
        Ok(status) => {
            // For debugging purposes, log status occasionally
            // Not implemented: NTC thermistor
            info!(
                "PD Status: Voltage={}mV, Current={}mA, Temp={}°C, PDP={}W",
                status.voltage_mv,
                status.current_ma,
                status.temperature,
                status.pdp_limit_w
            );
        },
        Err(e) => {
            info!("Failed to read AP33772S status: {:?}", e);
        }
    }
    let _ = ap33772s.request_voltage(&mut i2cdrv, PDVoltage::V5);
    // ap33772s.force_vout_off(&mut i2cdrv).unwrap();

    // Get PDO limits from connected source
    i2c_sel.set_high().unwrap(); // Enable USB PD for PDO query
    let (pdo_max_voltage, pdo_max_current) = ap33772s.get_pdo_limits();
    info!("PDO Limits: Max Voltage = {:.2}V, Max Current = {:.3}A", pdo_max_voltage, pdo_max_current);
    
    // Apply the more restrictive limit between config and PDO
    let effective_max_current = if pdo_max_current < max_current_limit { pdo_max_current } else { max_current_limit };
    info!("Effective Current Limit: {:.3}A (Config: {:.3}A, PDO: {:.3}A)", 
          effective_max_current, max_current_limit, pdo_max_current);
    println!("[Effective Limits] Voltage: {:.2}V  Current: {:.3}A", pdo_max_voltage, effective_max_current);

    // Select INA228
    i2c_sel.set_low().unwrap(); // Select INA228

    // Initialize INA228 sensor
    match ADCRANGE {
        true => write_ina228_reg16(&mut i2cdrv, 0x00, 0x0030)?, // Bit4: ADCRANGE=1(40.96mV), Bit5 Enables temperature compensation
        false => write_ina228_reg16(&mut i2cdrv, 0x00, 0x0020)?, // Bit4: ADCRANGE=0(163.84mV), Bit5 Enables temperature compensation
    }
    let read_value = read_ina228_reg16(&mut i2cdrv, 0x00)?;
    info!("INA228 Config Set to: {:04x}", read_value);

    // INA228 ADC Config
    let read_adc_config = read_ina228_reg16(&mut i2cdrv, 0x01)?;
    info!("INA228 ADC Config Read: {:04x}", read_adc_config);
    let write_adc_config : u16 = (read_adc_config & 0xFFF8) | 0x04; // Clear bits 0-2, 0x00: 1avg, 0x02: 16avg, 0x03: 64avg
    write_ina228_reg16(&mut i2cdrv, 0x01, write_adc_config)?;
    let read_adc_config = read_ina228_reg16(&mut i2cdrv, 0x01)?;
    info!("INA228 ADC Config Set to: {:04x}", read_adc_config);


    // SHUNT_CAL
    let shunt_resistance = CONFIG.shunt_resistance.parse::<f32>().unwrap();
    let current_lsb = match ADCRANGE {
        true => {
            // 40.96mV range
            40.96 / 524_288.0
        },
        false => {
            // 163.84mV range
            163.84 / 524_288.0
        }
    };
    let shunt_cal_val = match ADCRANGE {
        true => 13107.2 * current_lsb * 1000_000.0 * shunt_resistance * 4.0, // 40.96mV range
        false => 13107.2 * current_lsb * 1000_000.0 * shunt_resistance, // 163.84mV range
    };
    let shunt_cal = shunt_cal_val as u16;
    info!("current_lsb={:?} shunt_cal_val={:?} shunt_cal={:?}", current_lsb, shunt_cal_val, shunt_cal);
    write_ina228_reg16(&mut i2cdrv, 0x02, shunt_cal)?;
    let read_shunt_cal = read_ina228_reg16(&mut i2cdrv, 0x02)?;
    info!("INA228 SHUNT_CAL Set to: {:04x}", read_shunt_cal);
    // Shunt Temperature Coefficient
    let shunt_temp_coefficient = CONFIG.shunt_temp_coefficient.parse::<u16>().unwrap();
    info!("Shunt Temperature Coefficient: {:?}", shunt_temp_coefficient);
    write_ina228_reg16(&mut i2cdrv, 0x03, shunt_temp_coefficient)?;
    let read_shunt_temp_coefficient = read_ina228_reg16(&mut i2cdrv, 0x03)?;
    info!("INA228 SHUNT_TEMP_COEFFICIENT Set to: {:04x}", read_shunt_temp_coefficient);

    // Temperature Measurement
    let temperature: f32 = read_ina228_reg16(&mut i2cdrv, 0x06)? as f32 * 7.8125;
    info!("Initial Temperature Read: {:.2}°C", temperature / 1000.0);

    // calibration read
    let mut average_current_offset :f32 = 0.0;
    let mut average_voltage_offset :f32 = 0.0;
    // let (current_offset, voltage_offset) = calibration(&mut i2cdrv, current_lsb)?;
    // average_current_offset = current_offset;

    // PWM
    let timer_config_out_current = TimerConfig::default().frequency(4.kHz().into())
        .resolution(esp_idf_hal::ledc::config::Resolution::Bits14);
    let timer_driver_0 = LedcTimerDriver::new(peripherals.ledc.timer0, &timer_config_out_current).unwrap();
    let mut pwm_driver = LedcDriver::new(peripherals.ledc.channel0, &timer_driver_0, peripherals.pins.gpio38).unwrap();
    pwm_driver.set_duty(0).expect("Set duty failure");
    let max_duty = pwm_driver.get_max_duty();
    info!("Max duty: {}", max_duty);

    let pd_config_offset = CONFIG.pd_config_offset.parse::<f32>().unwrap();    

    // Temperature Logs
    let mut clogs = CurrentRecord::new();

    // Initialize logging for early debugging
    let mut wifi_enable : bool;
    let mut wifi_dev = wifi::wifi_connect(peripherals.modem, CONFIG.wifi_ssid, CONFIG.wifi_psk);

    if CONFIG.syslog_enable == "true" {
        // Initialize syslog logger to replace the default ESP logger
        println!("Initializing syslog logger...");
        thread::sleep(Duration::from_secs(5));
        
        match syslogger::init_logger(CONFIG.syslog_server, CONFIG.syslog_enable) {
            Ok(_) => {
                // Set log level for syslog
                log::set_max_level(log::LevelFilter::Info);
                println!("Syslog logger initialized successfully");
                info!("Syslog logger initialized successfully");
            },
            Err(e) => {
                // Fallback to ESP logger if syslog fails
                println!("Failed to initialize syslog logger: {:?}, using ESP logger instead", e);
                esp_idf_svc::log::EspLogger::initialize_default();
                log::set_max_level(log::LevelFilter::Info);
                info!("Failed to initialize syslog logger: {:?}, using ESP logger instead", e);
            }
        }
    } else {
        // syslog_enable is false, continue using default ESP console logger
        info!("Using default ESP console logger (syslog disabled)");
    }
    
    // NTP Server
    let sntp_conf = SntpConf {
        servers: ["time.aws.com",
                    "time.google.com",
                    "time.cloudflare.com",
                    "ntp.nict.jp"],
        operating_mode: OperatingMode::Poll,
        sync_mode: SyncMode::Immediate,
    };
    let ntp = EspSntp::new(&sntp_conf).unwrap();

    // NTP Sync
    // let now = SystemTime::now();
    // if now.duration_since(UNIX_EPOCH).unwrap().as_millis() < 1700000000 {
    info!("NTP Sync Start..");

    // wait for sync
    let mut sync_count = 0;
    while ntp.get_sync_status() != SyncStatus::Completed {
        sync_count += 1;
        if sync_count > 1000 {
            info!("NTP Sync Timeout");
            break;
        }
        thread::sleep(Duration::from_millis(10));
    }
    let now = SystemTime::now();
    let dt_now : DateTime<Utc> = now.into();
    let formatted = format!("{}", dt_now.format("%Y-%m-%d %H:%M:%S"));
    info!("NTP Sync Completed: {}", formatted);
        
    let mut txd =  Transfer::new(server_info);
    txd.start()?;

    // TouchPad
    let mut touchpad = TouchPad::new();
    touchpad.start();
    
    // ADC2-CH7 GPIO18 for Temperature
    let mut adc_temp = AdcDriver::new(peripherals.adc2)?;
    let mut adc_temp_config = AdcConfig {
        attenuation: DB_11,
        calibration: Calibration::Curve,
        .. AdcConfig::default()
    };
    let mut temp_pin = AdcChannelDriver::new(&mut adc_temp, peripherals.pins.gpio18, &mut adc_temp_config)?;

    // ADC1-CH8 GPIO9 for USB PD Voltage
    let mut adc_pd_voltage = AdcDriver::new(peripherals.adc1)?;
    let mut adc_pd_voltage_config = AdcConfig {
        attenuation: DB_11,
        calibration: Calibration::Curve,
        .. AdcConfig::default()
    };
    let mut usb_pd_pin = AdcChannelDriver::new(&mut adc_pd_voltage, peripherals.pins.gpio9, &mut adc_pd_voltage_config)?;
    
    // PID Controller
    let pid_kp = CONFIG.pid_kp.parse::<f32>().unwrap();
    let pid_ki = CONFIG.pid_ki.parse::<f32>().unwrap();
    let pid_kd = CONFIG.pid_kd.parse::<f32>().unwrap();
    let pwm_offset = CONFIG.pwm_offset.parse::<u32>().unwrap();
    info!("PID Controller: KP={} KI={} KD={}", pid_kp, pid_ki, pid_kd);
    let mut pid = PIDController::new(pid_kp, pid_ki, pid_kd, 0.0);

    // Start Display
    dp.enable_display(true);

    // TouchPad Long Press
    touchpad.set_press_threshold(Key::Center, 1000, false);
    touchpad.set_press_threshold(Key::Up, 300, true);
    touchpad.set_press_threshold(Key::Down, 300, true);

    // loop
    let mut measurement_count : u32 = 0;
    let mut logging_start = false;
    let mut load_start = false;
    let mut calibration_start = false;
    
    // Load last voltage setting from NVS
    let mut set_output_voltage = match load_voltage_from_nvs() {
        Ok(voltage) => {
            // Ensure voltage is within PDO limits
            if voltage > pdo_max_voltage {
                info!("Loaded voltage {:.3}V exceeds PDO limit {:.3}V, using limit", voltage, pdo_max_voltage);
                pdo_max_voltage
            } else {
                voltage
            }
        },
        Err(e) => {
            info!("Failed to load voltage from NVS: {:?}, using 0.0V", e);
            0.0
        }
    };
    
    info!("Initial voltage setting: {:.3}V", set_output_voltage);
    let mut previous_set_output_voltage = 0.0;
    
    // Set initial voltage display
    dp.set_output_voltage(set_output_voltage);
    
    let mut pwm_duty : u32;
    loop {
        thread::sleep(Duration::from_millis(10));

        let mut start_stop_btn = false;
        measurement_count += 1;
        if measurement_count % 10 == 0 {
            let key_event = touchpad.get_key_event_and_clear();
            for key in &key_event {
                match key {
                    KeyEvent::CenterKeyDown => {
                        // Clear error messages when center key is pressed
                        dp.set_message("".to_string(), false, 0);
                        info!("Error message cleared by center key press");
                    },
                    KeyEvent::CenterKeyDownLong => {
                        if start_stop_btn == false {
                            start_stop_btn = true;
                        }
                        else {
                            start_stop_btn = false;
                        } 
                    },
                    KeyEvent::UpKeyDown => {
                        set_output_voltage += 0.1;
                        if set_output_voltage > pdo_max_voltage {
                            set_output_voltage = pdo_max_voltage;
                        }
                        dp.set_output_voltage(set_output_voltage);
                    },
                    KeyEvent::RightKeyDown => {
                        set_output_voltage += 0.01;
                        if set_output_voltage > pdo_max_voltage {
                            set_output_voltage = pdo_max_voltage;
                        }
                        dp.set_output_voltage(set_output_voltage);
                    },
                    KeyEvent::UpKeyDownLong => {
                        set_output_voltage = ((set_output_voltage + 1.0) as u32) as f32;
                        if set_output_voltage > pdo_max_voltage {
                            set_output_voltage = pdo_max_voltage;
                        }
                        dp.set_output_voltage(set_output_voltage);
                    },
                    KeyEvent::DownKeyDown => {
                        set_output_voltage -= 0.1;
                        if set_output_voltage < 0.0 {
                            set_output_voltage = 0.0;
                        }
                        dp.set_output_voltage(set_output_voltage);
                    },
                    KeyEvent::LeftKeyDown => {
                        set_output_voltage -= 0.01;
                        if set_output_voltage < 0.0 {
                            set_output_voltage = 0.0;
                        }
                        dp.set_output_voltage(set_output_voltage);
                    },
                    KeyEvent::DownKeyDownLong => {
                        set_output_voltage = ((set_output_voltage - 1.0) as u32) as f32;
                        if set_output_voltage < 0.0 {
                            set_output_voltage = 0.0;
                        }
                        dp.set_output_voltage(set_output_voltage);
                    },
                    KeyEvent::UpDownKeyCombinationDown => {
                        // Calibration
                        calibration_start = true;
                    },
                    _ => {},
                }
            }
            // if key_event.len() > 0 {
            //     dp.set_message("".to_string(), false);
            // }
        }
        if start_stop_btn == true {
            if load_start == true {
                // to Stop
                logging_start = false;
                load_start = false;
                usbpd_control(&mut i2c_sel, &mut ap33772s, &mut i2cdrv, 0.0, pd_config_offset);
                // clogs.dump();
                // clogs.clear();
            }
            else {
                // to Start
                logging_start = true;
                load_start = true;
                measurement_count = 0;
                previous_set_output_voltage = 0.0;
                info!("Logging and Sending Start..");
                
                // Save current voltage setting to NVS when starting
                if let Err(e) = save_voltage_to_nvs(set_output_voltage) {
                    info!("Failed to save voltage to NVS: {:?}", e);
                }
                
                pid.reset();
                clogs.clear();
                dp.enable_display(true);
            }
        }

        let rssi = wifi::get_rssi();
        if rssi == 0 {
            wifi_enable = false;
            if measurement_count % 1000 == 0 {
                wifi_reconnect(&mut wifi_dev.as_mut().unwrap());
            }
        }
        else {
            wifi_enable = true;
        }

        if wifi_enable == false {
            dp.set_wifi_status(WifiStatus::Disconnected);
        }
        else {
            dp.set_wifi_status(WifiStatus::Connected);
        }
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

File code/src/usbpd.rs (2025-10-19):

// AP33772S USB PD SINK Controller driver wrapper for ESP32
// SPDX-License-Identifier: MIT
// Copyright (c) 2024 Hiroshi Nakajima

//! This module provides a wrapper around the ap33772s-driver crate
//! specifically for ESP32 platforms using esp-idf-hal.

#![allow(dead_code)]

use log::*;
use std::thread;
use std::time::Duration;
use esp_idf_hal::i2c;
use esp_idf_hal::delay::BLOCK;
use embedded_hal::i2c::{I2c, ErrorType};
use embedded_hal::delay::DelayNs;
use esp_idf_sys::EspError;

// Import the driver and types from the ap33772s-driver crate (note: hyphens become underscores)
use ap33772s_driver::AP33772S as GenericAP33772S;
pub use ap33772s_driver::{PDVoltage, PDOInfo, PDStatus};

// Error type wrapper for embedded-hal compatibility
#[derive(Debug)]
pub struct I2cError(pub EspError);

impl embedded_hal::i2c::Error for I2cError {
    fn kind(&self) -> embedded_hal::i2c::ErrorKind {
        embedded_hal::i2c::ErrorKind::Other
    }
}

// Delay implementation for ESP32 using std::thread::sleep
pub struct StdDelay;

impl DelayNs for StdDelay {
    fn delay_ns(&mut self, ns: u32) {
        if ns > 0 {
            let duration = Duration::from_nanos(ns as u64);
            thread::sleep(duration);
        }
    }
}

/// I2C wrapper to adapt esp-idf-hal I2cDriver to embedded-hal traits
struct I2cWrapper<'a, 'b> {
    driver: &'a mut i2c::I2cDriver<'b>,
}

impl<'a, 'b> I2cWrapper<'a, 'b> {
    fn new(driver: &'a mut i2c::I2cDriver<'b>) -> Self {
        Self { driver }
    }
}

impl<'a, 'b> ErrorType for I2cWrapper<'a, 'b> {
    type Error = I2cError;
}

impl<'a, 'b> I2c for I2cWrapper<'a, 'b> {
    fn write(&mut self, address: u8, bytes: &[u8]) -> Result<(), Self::Error> {
        self.driver.write(address, bytes, BLOCK)
            .map_err(I2cError)
    }

    fn read(&mut self, address: u8, buffer: &mut [u8]) -> Result<(), Self::Error> {
        self.driver.read(address, buffer, BLOCK)
            .map_err(I2cError)
    }

    fn transaction(
        &mut self,
        address: u8,
        operations: &mut [embedded_hal::i2c::Operation<'_>],
    ) -> Result<(), Self::Error> {
        for operation in operations {
            match operation {
                embedded_hal::i2c::Operation::Write(bytes) => {
                    self.write(address, bytes)?;
                }
                embedded_hal::i2c::Operation::Read(buffer) => {
                    self.read(address, buffer)?;
                }
            }
        }
        Ok(())
    }
}

/// ESP32-specific wrapper for the AP33772S driver
/// 
/// This wrapper provides the same interface as the original usbpd.rs
/// but uses the generic ap33772s-driver crate internally.
pub struct AP33772S {
    driver: GenericAP33772S,
}

impl AP33772S {
    /// Create a new AP33772S driver instance
    pub fn new() -> Self {
        AP33772S {
            driver: GenericAP33772S::new(),
        }
    }

    /// Initialize the AP33772S controller
    pub fn init(&mut self, i2cdrv: &mut i2c::I2cDriver) -> anyhow::Result<()> {
        info!("Initializing AP33772S...");
        
        // Create wrapper for the I2C driver
        let mut i2c_wrapper = I2cWrapper::new(i2cdrv);
        
        match self.driver.init(&mut i2c_wrapper) {
            Ok(()) => {
                info!("AP33772S initialized successfully");
                // Log available PDOs
                for pdo in self.driver.get_pdo_list() {
                    let is_epr = pdo.pdo_index >= 8;
                    info!("PDO {}: {}mV, {}mA, {}mW, {}",
                        pdo.pdo_index,
                        pdo.voltage_mv,
                        pdo.current_ma,
                        pdo.max_power_mw,
                        if pdo.is_fixed { 
                            if is_epr { "Fixed EPR" } else { "Fixed SPR" }
                        } else { 
                            if is_epr { "AVS APDO" } else { "PPS APDO" }
                        }
                    );
                }
                info!("Found {} PDOs", self.driver.get_pdo_list().len());
                Ok(())
            },
            Err(e) => {
                error!("Failed to initialize AP33772S: {:?}", e);
                Err(anyhow::anyhow!("AP33772S initialization failed"))
            }
        }
    }
    
    /// Perform a hard reset of the PD connection
    pub fn hard_reset(&self, i2cdrv: &mut i2c::I2cDriver) -> anyhow::Result<()> {
        info!("Performing hard reset on AP33772S...");
        let mut i2c_wrapper = I2cWrapper::new(i2cdrv);
        
        match self.driver.hard_reset(&mut i2c_wrapper) {
            Ok(()) => {
                // Wait for reset to complete
                thread::sleep(Duration::from_millis(500));
                info!("AP33772S hard reset complete");
                Ok(())
            },
            Err(e) => {
                error!("Hard reset failed: {:?}", e);
                Err(anyhow::anyhow!("Hard reset failed"))
            }
        }
    }

    /// Request specific voltage from the USB PD source using predefined PDO index
    pub fn request_voltage(&self, i2cdrv: &mut i2c::I2cDriver, voltage: PDVoltage) -> anyhow::Result<()> {
        info!("Requesting voltage: {:?}", voltage);
        let mut i2c_wrapper = I2cWrapper::new(i2cdrv);
        let mut delay = StdDelay;
        
        match self.driver.request_voltage(&mut i2c_wrapper, &mut delay, voltage) {
            Ok(()) => {
                info!("Voltage request successful");
                Ok(())
            },
            Err(e) => {
                error!("Voltage request failed: {:?}", e);
                Err(anyhow::anyhow!("Voltage request failed"))
            }
        }
    }
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

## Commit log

2025-09-15 Change partition type
    [partitions.csv]
2025-09-28 Added NVS (Non-Volatile Storage) functionality to save the last set voltage when load starts and restore it as the initial voltage setting on next boot.
2025-09-28 Add hardware data
    [adoptpr-r2.kicad_sch, adoptpr.kicad_sch, body.3mf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]
2025-10-13 Fixed BOM list and README
    [bom.csv]
2025-10-19 for update ap33772s-driver
2025-10-19 update ap33772s-driver

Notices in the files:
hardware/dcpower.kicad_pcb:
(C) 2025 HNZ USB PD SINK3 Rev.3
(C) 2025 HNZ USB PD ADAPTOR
